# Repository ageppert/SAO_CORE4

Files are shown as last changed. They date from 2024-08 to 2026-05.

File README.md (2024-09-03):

# SAO_CORE4

A Nibble of Core Memory

Follow this project at: https://hackaday.io/project/197235-sao-core4-a-nibble-of-core-memory-with-i2c

Hardware Version 0.2.0 - Work in progres - reducing board size - add button - simplify.

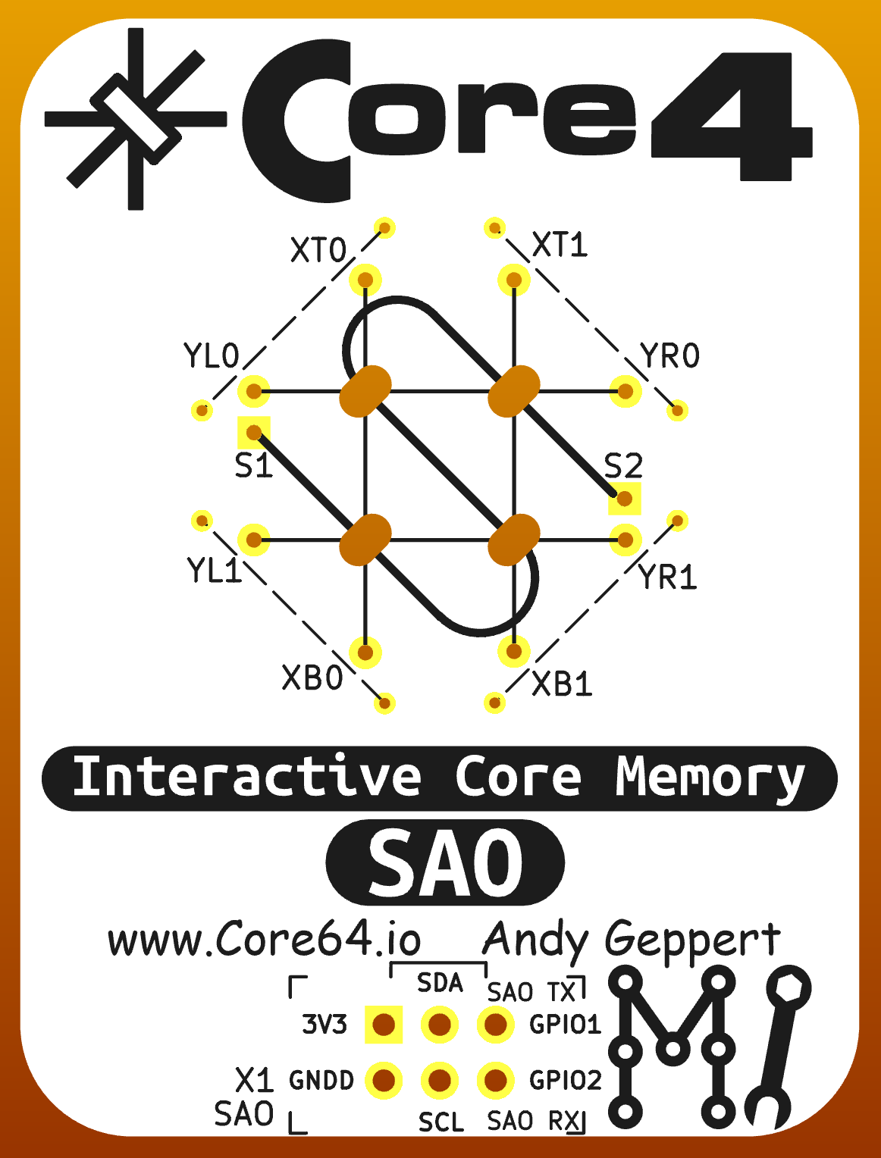
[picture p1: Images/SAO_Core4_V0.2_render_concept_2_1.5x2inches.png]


Hardware Version 0.1.1 hand reworked prototype, simplified and re-routed row drive transistor signals to simplify firmware development. This is the version that is currently the functional prototype. These changes will be in 0.2.0.

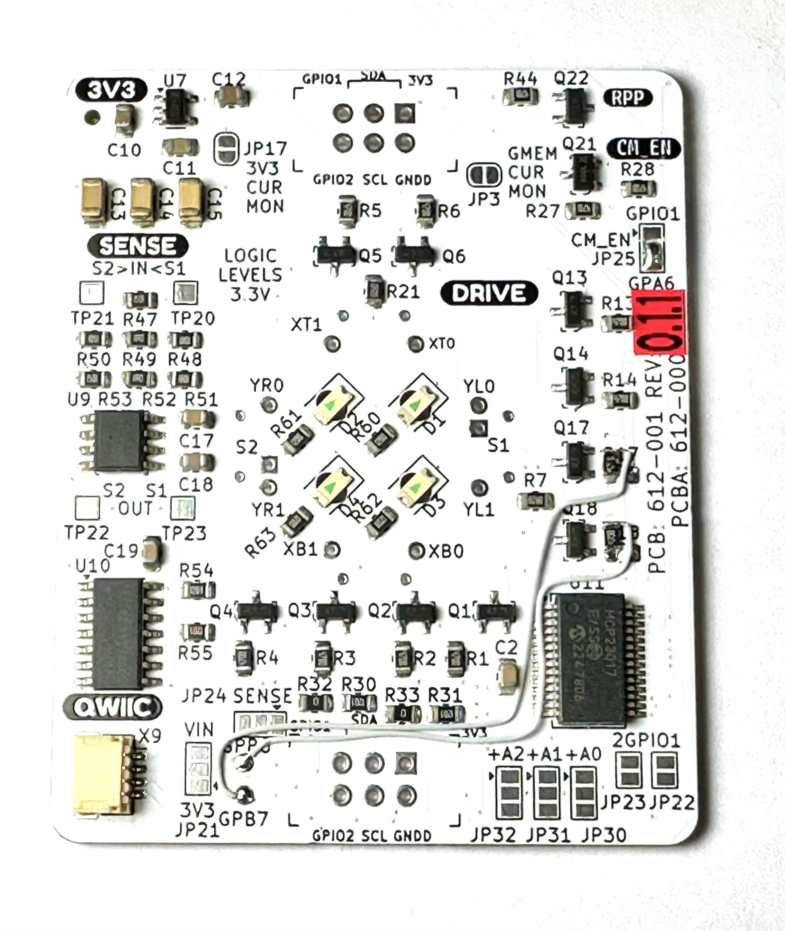
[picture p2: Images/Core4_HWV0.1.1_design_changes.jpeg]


Hardware Version 0.1 as prototyped

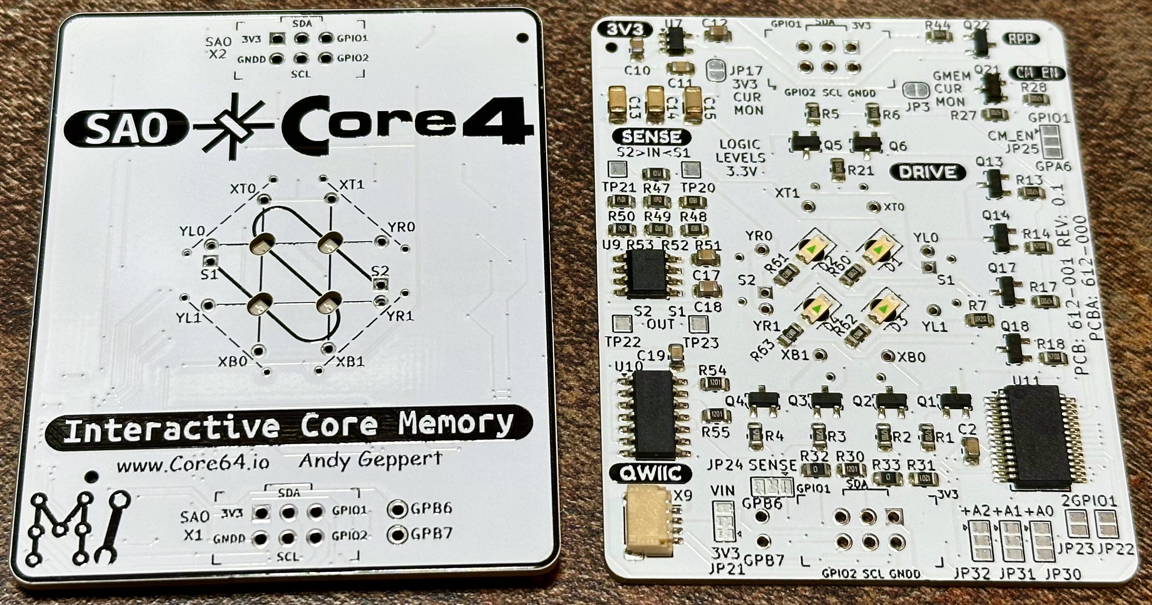
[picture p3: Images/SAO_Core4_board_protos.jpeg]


Hardware Version 0.1 render

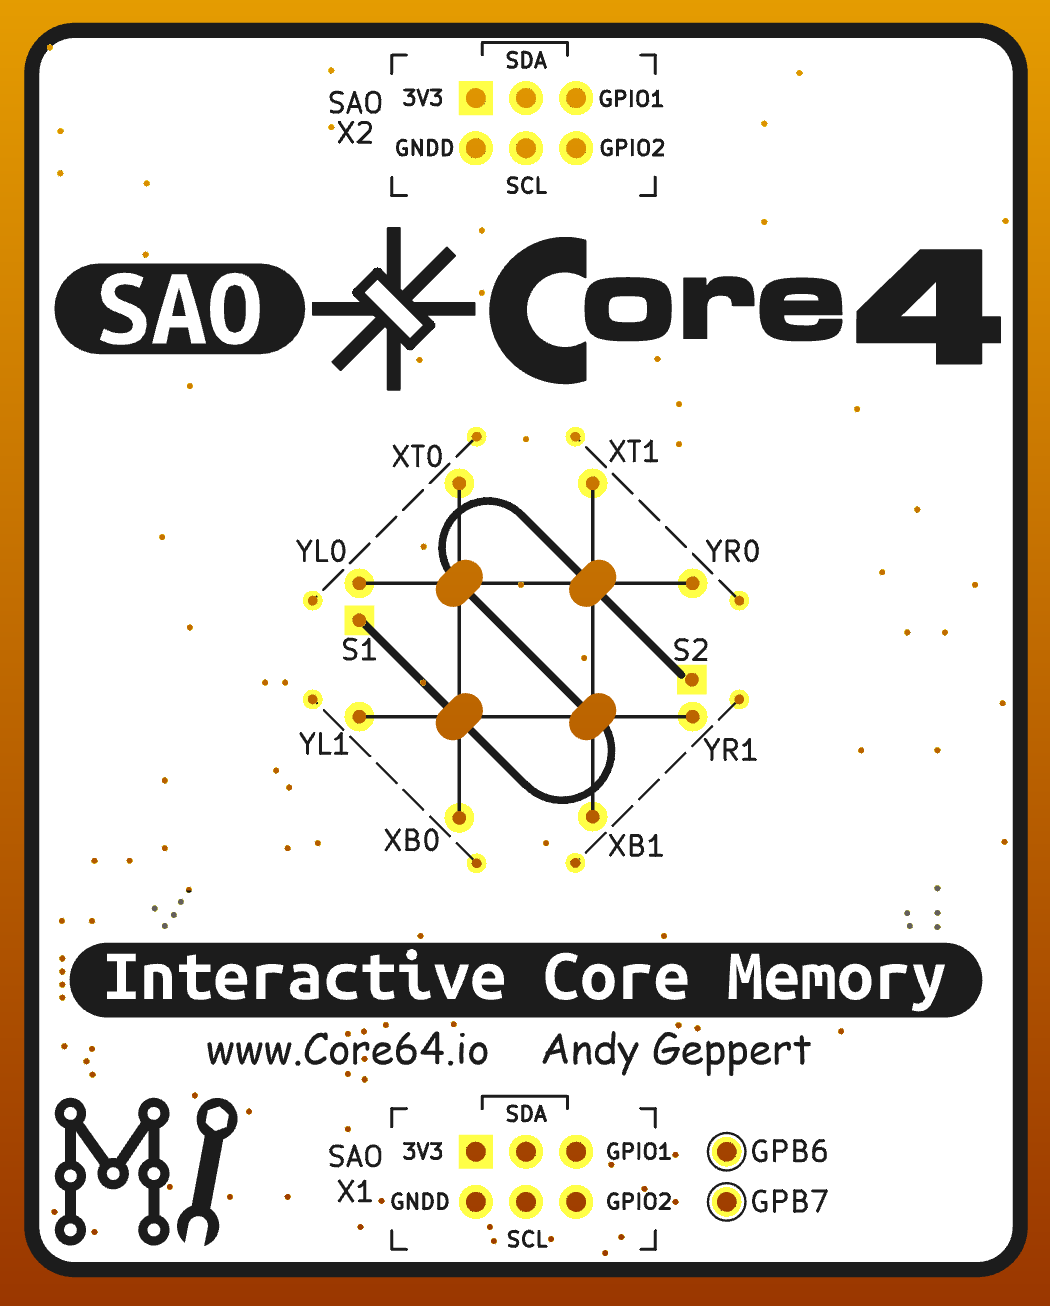
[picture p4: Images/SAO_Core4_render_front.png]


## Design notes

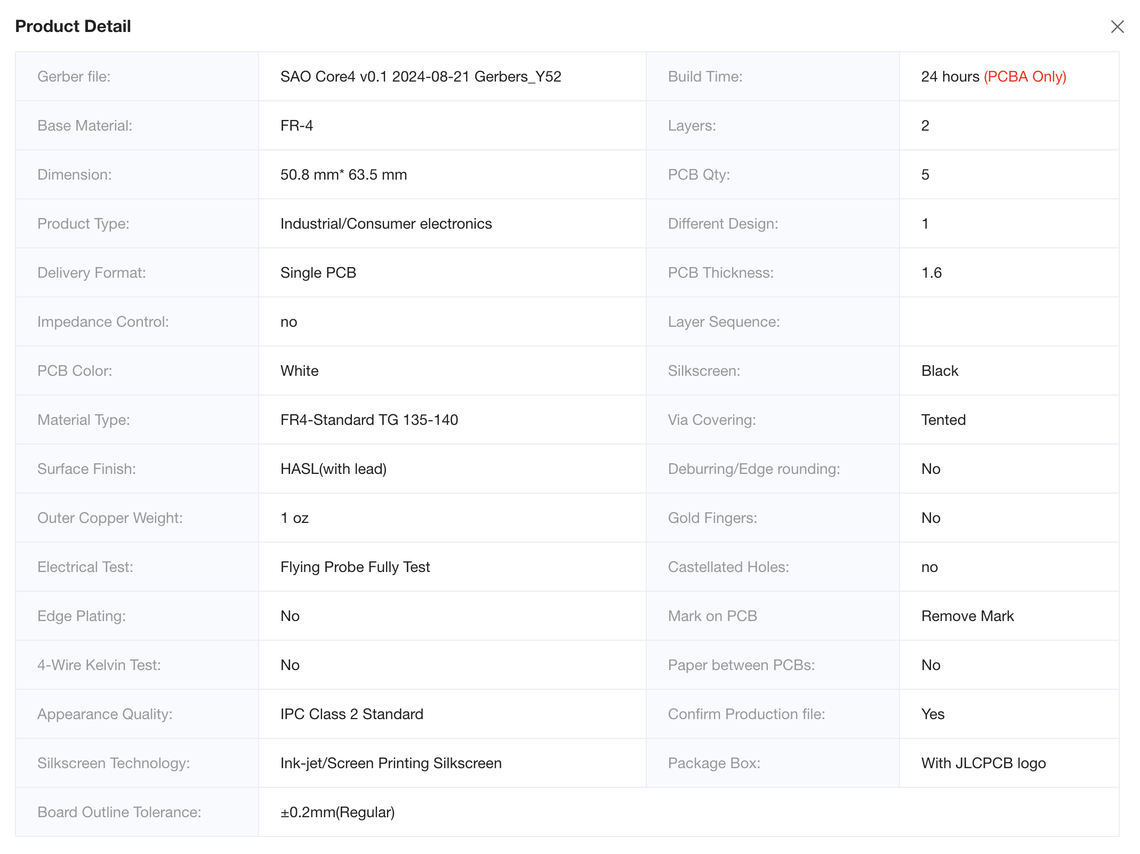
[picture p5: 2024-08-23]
Electronic Design/SAO_Core4_V0.1 Manufacturing (Qty 5)/Production Confirmation PCB Specs.png

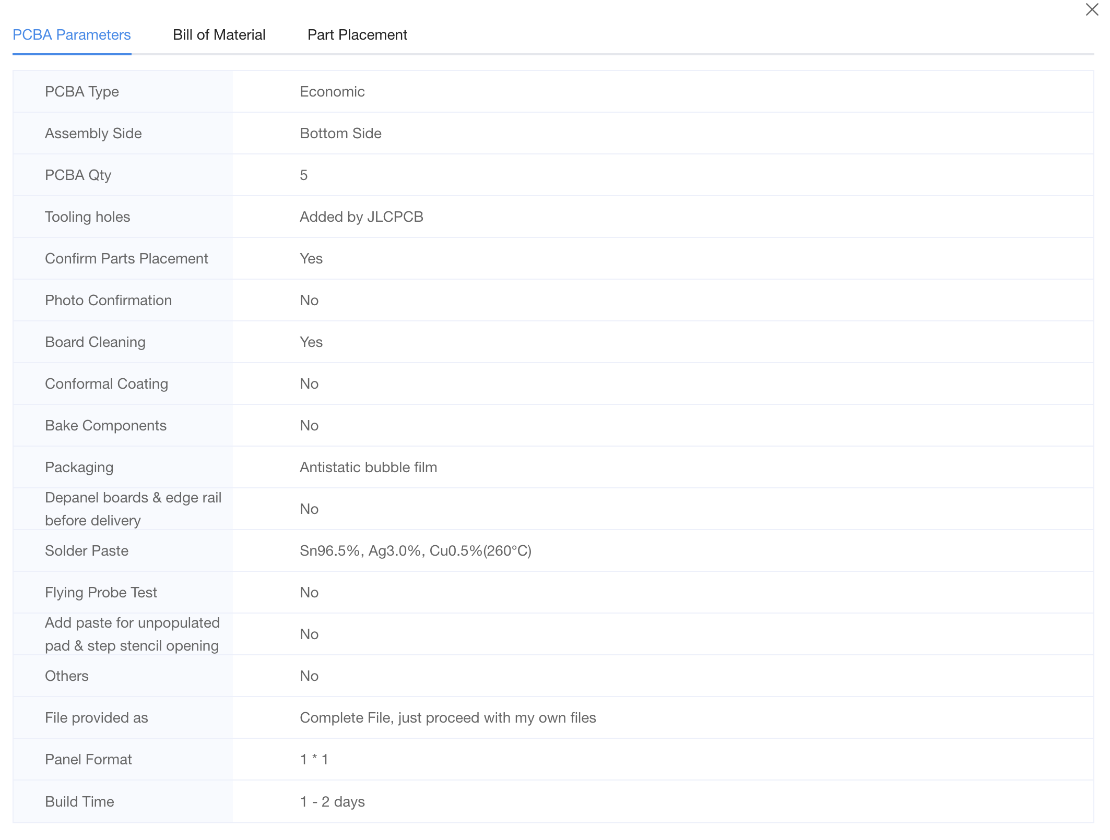
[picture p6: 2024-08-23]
Electronic Design/SAO_Core4_V0.1 Manufacturing (Qty 5)/Production Confirmation PCBA Specs.png

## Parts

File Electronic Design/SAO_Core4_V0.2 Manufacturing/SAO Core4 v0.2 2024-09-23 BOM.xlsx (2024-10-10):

Comment | Designator | Footprint | LCSC Part Number | Substituted
0.1uF | C2, C17, C19 | Capacitor_SMD:C_0805_2012Metric | C28233 | 3
1uF | C10, C12 | Capacitor_SMD:C_0805_2012Metric | C28323 | 2
0.01uF | C11 | Capacitor_SMD:C_0805_2012Metric | C1710 | 1
220uF | C13, C14, C15 | Capacitor_SMD:C_1206_3216Metric | C412252 | 3
10uF | C18 | Capacitor_SMD:C_0805_2012Metric | C17024 | 1
LED | D1, D2, D3, D4 | Andy_Footprint_Library:LED_1206_3216Metric_RevMnt_Hole1.8x2.4mm_custom | C3646936 | 4
MMBT4403LT1G | Q1, Q3, Q5, Q13, Q17 | digikey-footprints:SOT-23-3 | C78864 | 5
MMBT4401LT1G | Q2, Q4, Q6, Q14, Q18 | digikey-footprints:SOT-23-3 | C31776 | 5
Q_NMOS_DGS_AO3400A | Q21 | digikey-footprints:SOT-23-3 | C20917 | 1
470 | R1, R2, R3, R4, R5, R6, R13, R14, R17, R18, R28 | Resistor_SMD:R_0805_2012Metric | C17710 | 11
6R8-5% | R7, R21 | Resistor_SMD:R_0805_2012Metric | C17774 | 2
10K | R27, R30, R31, R54, R55 | Resistor_SMD:R_0805_2012Metric | C17414 | 5
1K5-1% | R47, R50, R53 | Resistor_SMD:R_0805_2012Metric | C4310 | 3
1K8-1% | R48, R51 | Resistor_SMD:R_0805_2012Metric | C17398 | 2
11-1% | R49, R52 | Resistor_SMD:R_0805_2012Metric | C17430 | 2
120 | R61, R62, R63, R64 | Resistor_SMD:R_0805_2012Metric | C17437 | 4
Button Edge EVQ-P7J01P | SW1 | Andy_Footprint_Library:SMD4_SW_EVQP7J_PAN | C2828254 | 1
SSP9193-33M5R | U7 | Package_TO_SOT_SMD:SOT-23-5 | C411022 | 1
LM393 | U9 | Andy_Footprint_Library:SOIC-8_W3.9mm | C7955 | 1
SN74HC02DR | U10 | Package_SO:SOIC-14_3.9x8.7mm_P1.27mm | C6809 | 1
MCP23017_SS | U11 | Package_SO:SSOP-28_5.3x10.2mm_P0.65mm | C506653 | 1

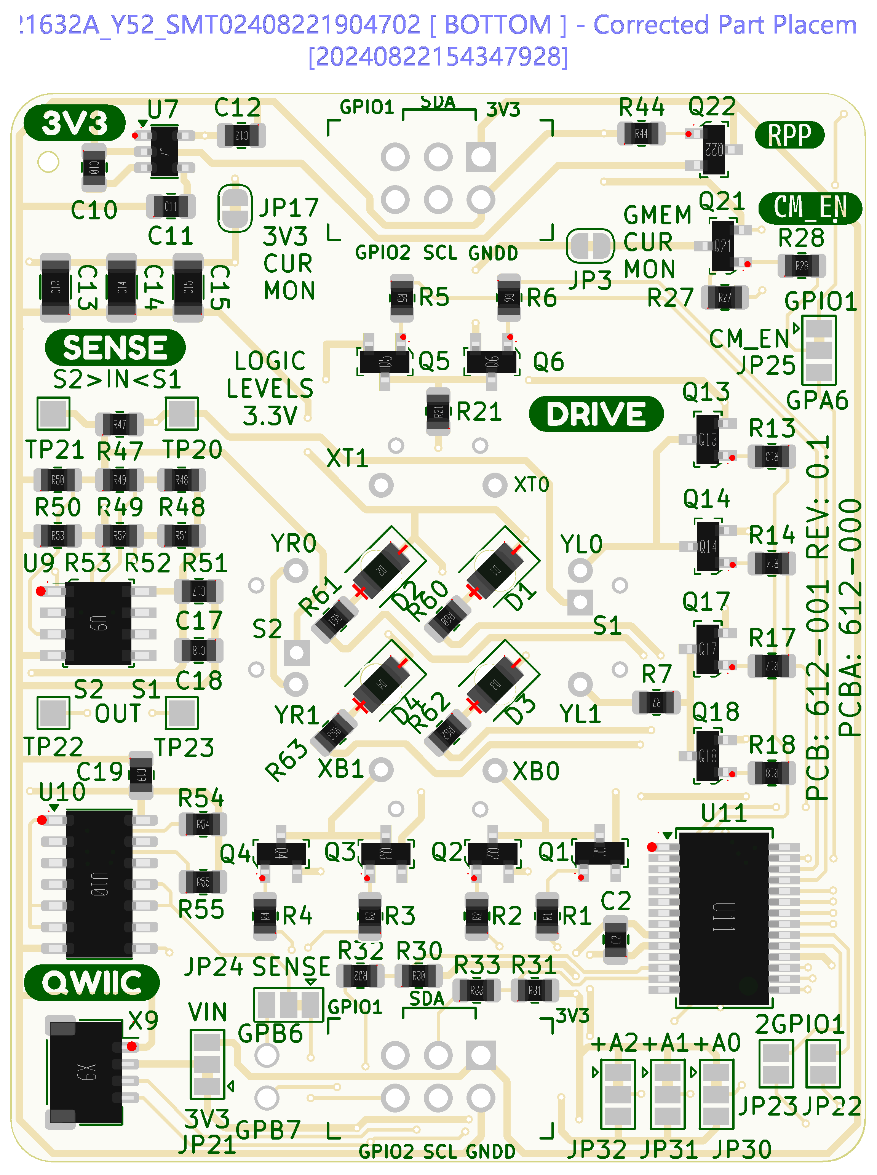
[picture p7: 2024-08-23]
Electronic Design/SAO_Core4_V0.1 Manufacturing (Qty 5)/Production Confirmation Parts Placement.png

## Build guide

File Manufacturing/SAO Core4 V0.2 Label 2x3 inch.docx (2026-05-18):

SAO CORE4 KIT V0.2 [ ] Qty 1, SAO Core4 PCBA [ ] Qty 1, SAO Shrouded Header 2x3 pin [ ] Qty 1, Enameled Wire, 32AWG, 600mm (24 in.) [ ] Qty 6, Ferrite Core Memory bits [ ] Qty 3, Screen Protector 17x17mm [ ] Qty 1, Magnetic Stylus, 3mm magnets https://hackaday.io/project/197235 https://github.com/ageppert/SAO_CORE4 | SAO CORE4 KIT V0.2 [ ] Qty 1, SAO Core4 PCBA [ ] Qty 1, SAO Shrouded Header 2x3 pin [ ] Qty 1, Enameled Wire, 32AWG, 600mm (24 in.) [ ] Qty 6, Ferrite Core Memory bits [ ] Qty 3, Screen Protector 17x17mm [ ] Qty 1, Magnetic Stylus, 3mm magnets https://hackaday.io/project/197235 https://github.com/ageppert/SAO_CORE4
SAO CORE4 KIT V0.2 [ ] Qty 1, SAO Core4 PCBA [ ] Qty 1, SAO Shrouded Header 2x3 pin [ ] Qty 1, Enameled Wire, 32AWG, 600mm (24 in.) [ ] Qty 6, Ferrite Core Memory bits [ ] Qty 3, Screen Protector 17x17mm [ ] Qty 1, Magnetic Stylus, 3mm magnets https://hackaday.io/project/197235 https://github.com/ageppert/SAO_CORE4 | SAO CORE4 KIT V0.2 [ ] Qty 1, SAO Core4 PCBA [ ] Qty 1, SAO Shrouded Header 2x3 pin [ ] Qty 1, Enameled Wire, 32AWG, 600mm (24 in.) [ ] Qty 6, Ferrite Core Memory bits [ ] Qty 3, Screen Protector 17x17mm [ ] Qty 1, Magnetic Stylus, 3mm magnets https://hackaday.io/project/197235 https://github.com/ageppert/SAO_CORE4
SAO CORE4 KIT V0.2 [ ] Qty 1, SAO Core4 PCBA [ ] Qty 1, SAO Shrouded Header 2x3 pin [ ] Qty 1, Enameled Wire, 32AWG, 600mm (24 in.) [ ] Qty 6, Ferrite Core Memory bits [ ] Qty 3, Screen Protector 17x17mm [ ] Qty 1, Magnetic Stylus, 3mm magnets https://hackaday.io/project/197235 https://github.com/ageppert/SAO_CORE4 | SAO CORE4 KIT V0.2 [ ] Qty 1, SAO Core4 PCBA [ ] Qty 1, SAO Shrouded Header 2x3 pin [ ] Qty 1, Enameled Wire, 32AWG, 600mm (24 in.) [ ] Qty 6, Ferrite Core Memory bits [ ] Qty 3, Screen Protector 17x17mm [ ] Qty 1, Magnetic Stylus, 3mm magnets https://hackaday.io/project/197235 https://github.com/ageppert/SAO_CORE4
SAO CORE4 KIT V0.2 [ ] Qty 1, SAO Core4 PCBA [ ] Qty 1, SAO Shrouded Header 2x3 pin [ ] Qty 1, Enameled Wire, 32AWG, 600mm (24 in.) [ ] Qty 6, Ferrite Core Memory bits [ ] Qty 3, Screen Protector 17x17mm [ ] Qty 1, Magnetic Stylus, 3mm magnets https://hackaday.io/project/197235 https://github.com/ageppert/SAO_CORE4 | SAO CORE4 KIT V0.2 [ ] Qty 1, SAO Core4 PCBA [ ] Qty 1, SAO Shrouded Header 2x3 pin [ ] Qty 1, Enameled Wire, 32AWG, 600mm (24 in.) [ ] Qty 6, Ferrite Core Memory bits [ ] Qty 3, Screen Protector 17x17mm [ ] Qty 1, Magnetic Stylus, 3mm magnets https://hackaday.io/project/197235 https://github.com/ageppert/SAO_CORE4
SAO CORE4 KIT V0.2 [ ] Qty 1, SAO Core4 PCBA [ ] Qty 1, SAO Shrouded Header 2x3 pin [ ] Qty 1, Enameled Wire, 32AWG, 600mm (24 in.) [ ] Qty 6, Ferrite Core Memory bits [ ] Qty 3, Screen Protector 17x17mm [ ] Qty 1, Magnetic Stylus, 3mm magnets https://hackaday.io/project/197235 https://github.com/ageppert/SAO_CORE4 | SAO CORE4 KIT V0.2 [ ] Qty 1, SAO Core4 PCBA [ ] Qty 1, SAO Shrouded Header 2x3 pin [ ] Qty 1, Enameled Wire, 32AWG, 600mm (24 in.) [ ] Qty 6, Ferrite Core Memory bits [ ] Qty 3, Screen Protector 17x17mm [ ] Qty 1, Magnetic Stylus, 3mm magnets https://hackaday.io/project/197235 https://github.com/ageppert/SAO_CORE4

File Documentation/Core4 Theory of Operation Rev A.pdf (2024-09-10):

.io

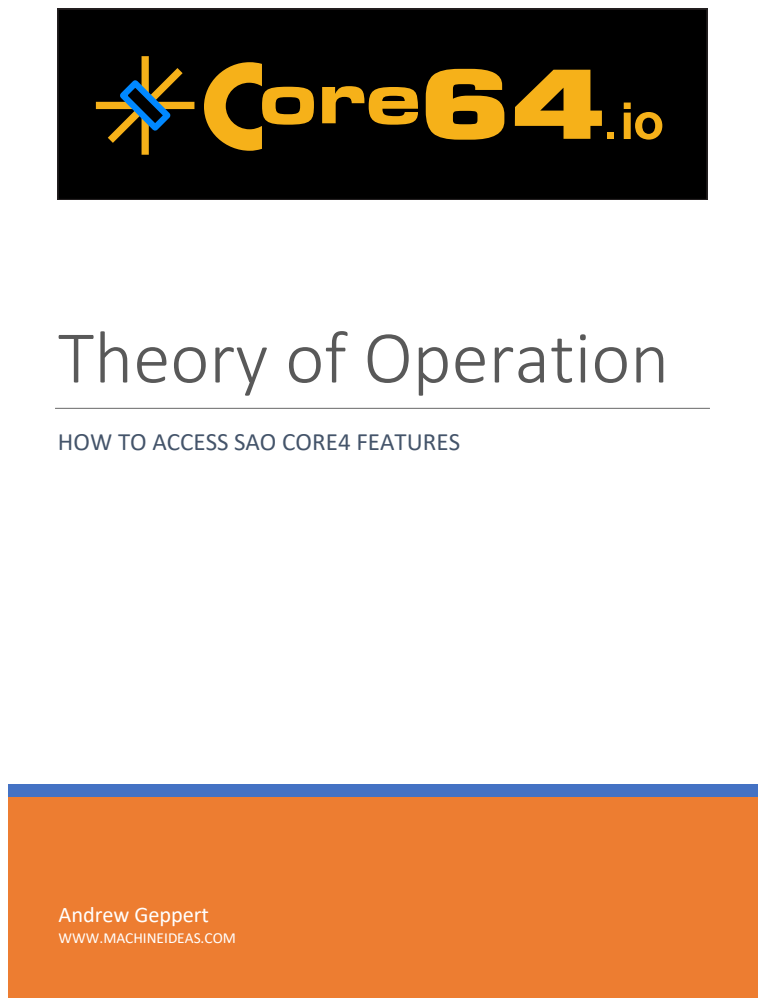
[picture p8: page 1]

Theory of Operation

HOW TO ACCESS SAO CORE4 FEATURES

Andrew Geppert
WWW.MACHINEIDEAS.COM

Core4 Theory of Operation | www.Core64.io | 2

## 1. TABLE OF CONTENTS

## 2. Version History of This Guide

Revision | Description | Author | Date
A | First draft | Andy Geppert | 2024-09-10

The latest version of this and related Core4 details at: https://github.com/ageppert/SAO_CORE4

Demo video on YouTube: https://www.youtube.com/watch?v=id1_PEvV3Vw

Concept and design by Andy Geppert at www.MachineIdeas.com

## 3. Important Cautions and Warnings

Beware the ESD monster!

Core4 Maximum battery pack voltage: 5.5 VDC All kits have minimum working voltage: 3 VDC

CORES are fragile! Don’t crush them.

CORES are small! Don’t lose them.

⚠ These caution symbols point out important things to help ensure your assembly goes smoothly!

## 4. Introduction

This guide covers the theory of operation and how to interface with the SAO Core4.

## 5. Control Signals

Control of the core matrix and LEDs is through an SAO port. Learn more about the SAO standard: https://docs.google.com/document/d/1EJqvkkLMAPsQ9VWF5A4elWoi0qMlKyr5Giw5rqRmtnM/edit?usp=sharing

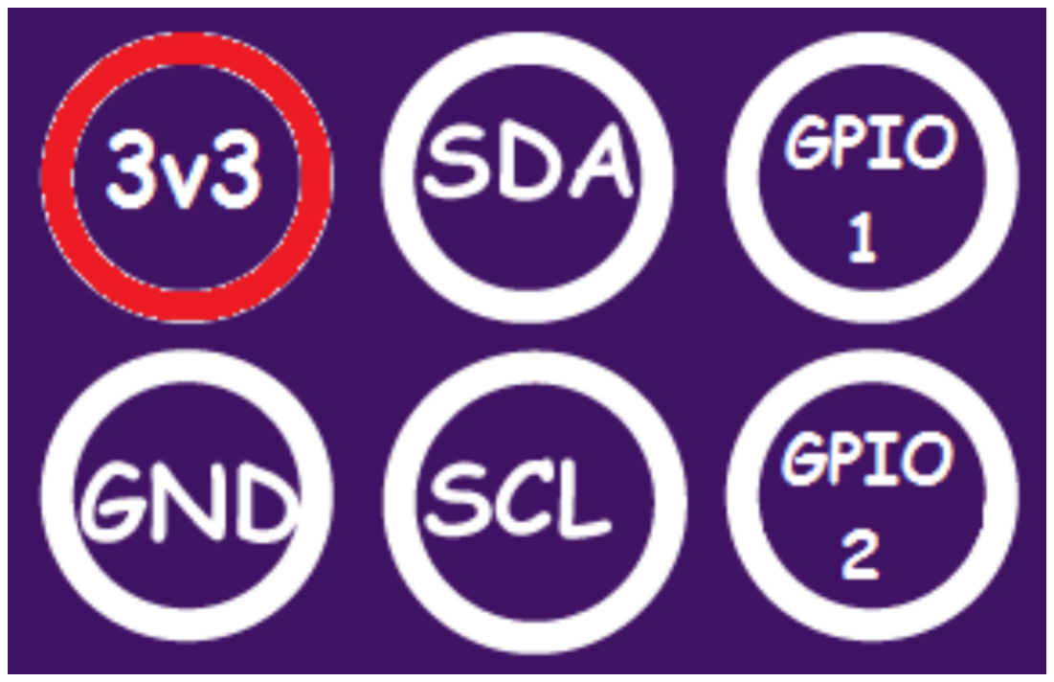
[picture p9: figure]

The I2C signals (SDA and SCL) connect to a single MCP23017 I2C IO Expander with a default address of 0x27 (Decimal 39). The sixteen MCP23017 GPIOs are all meant to be configured as outputs for use with Core4. These outputs are:
- 4 LEDs (high to enable)
- 10 core matrix drive transistors
- 1 common core memory drive enable MOSFET
- 1 sense circuit reset

GPIO 1 is used for an optional input button, to be configured with the associated MCU input set with pull-up enabled. When the button is pressed, GPIO 1 is expected to transition from high to low.

GPIO 2 is needed as the Sense signal input into the associated MCU. This is normally low, but goes high when a core changes state.

## 6. Controlling the LEDS

The LEDs are controlled by the MCP23017 output lines. High to turn on the LED, low to turn off.

PCBA Hardware Version 0.1.x:
GPB2 is LED 1, aka Pixel 0
GPB3 is LED 2, aka Pixel 1
GPB4 is LED 3, aka Pixel 2 GPB5 is LED 4, aka Pixel 3

⚠ An external MCU is required to operate SAO Core4. All control logic is 3.3 Volts.

## 7. Controlling Core Memory

Introduction

Core memory can only be written to. It is non-volatile. But it requires a write in order to read the state of the core. This is called a “destructive read.”

If the magnetic field of a core changes, when written too, there is a very small voltage induced in the sense wire, which is common to all the cores. Thus, only a single core should be written to at one time, in order to be able to detect its state.

If a core changes state when written too, as indicated by the sense wire signal, the core will need to be written again to the prior state.

A core state change will NOT occur if the magnetic stylus is near the given core. The absence of this state change, when it was expected to have occurred, is used by the MCU logic to determine the presence of the magnetic stylus.

Some great resources to learn more:
Curious Marc: https://www.youtube.com/watch?v=AwsInQLmjXc&t=1094s&ab_channel=CuriousMarc

Jerry Walker: https://www.youtube.com/watch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

Andy Geppert: https://www.youtube.com/watch?v=5HAyPMMNyDc&list=PLgr0YZUR4CSUvSYynSjwbAt1JiIod-NOV&ab_channel=AndyGeppert

Prepare to Sense

Follow along with the schematic to help out: https://github.com/ageppert/SAO_CORE4/tree/main/Electronic%20Design/SAO_Core4_V0.1.1%20Schematic

Prior to writing to a core, reset the sense circuit (sense signal output latch) by briefly driving CM_SNS_RST high via the MCP23017 IO Expander. Bring the CM_SNS_RST low, and make sure the Core Matrix Enable (CM_EN) is low at the same time.

Activate the Matrix

Each core is accessed by activating four transistors associated with the row and column which intersects with the chosen core. A final MOSFET is briefly enabled (CM_EN) to allow current to flow through the transistors. Additionally, a passive sense circuit will capture and store the sense signal, if present (when a core flips polarity), into the Sense Signal Output Latch.
- QxN (NPN) is normally low, high to activate matrix transistor.
- QxP (PNP) is normally high, low to activate matrix transistor.
- Q21 CM_EN MOSFET is normally low, high to activate the entire matrix.

Deactivate the Matrix

After the CM_EN is returned low, and the matrix driver transistors are disabled, the CM_SNS_PLS may be checked via GPIO2 of the SAO port. If this signal is high, that means a core changed polarity.

## 8. Troubleshooting

Each time a row or column is accessed, there should be a voltage drop across both matrix drive current limiting resistors, R7 and R21. The drop should be approximately 2 volts. If the voltage drop is not occurring then check:
- Continuity through the matrix wires.
- Correct transistors are being enabled.
- Core Memory Enable is enabled briefly.

If the current is flowing through the matrix wires, then check the sense output pulse signal (CM_SNS_PLS) when alternating the flow of current through a given core. Be sure to reset the sense circuit (CM_SNS_RST) between each alternate pulse of current.

There will be no sense signal detected if the current in two pulses to the core is in the same direction. It must alternate.

If the sense signal pulse is not present, verify continuity through the sense wire at either the solder pads S1 and S2 or the open ends of R47.

You may also find support here: https://discord.gg/nPcTNNfMmd

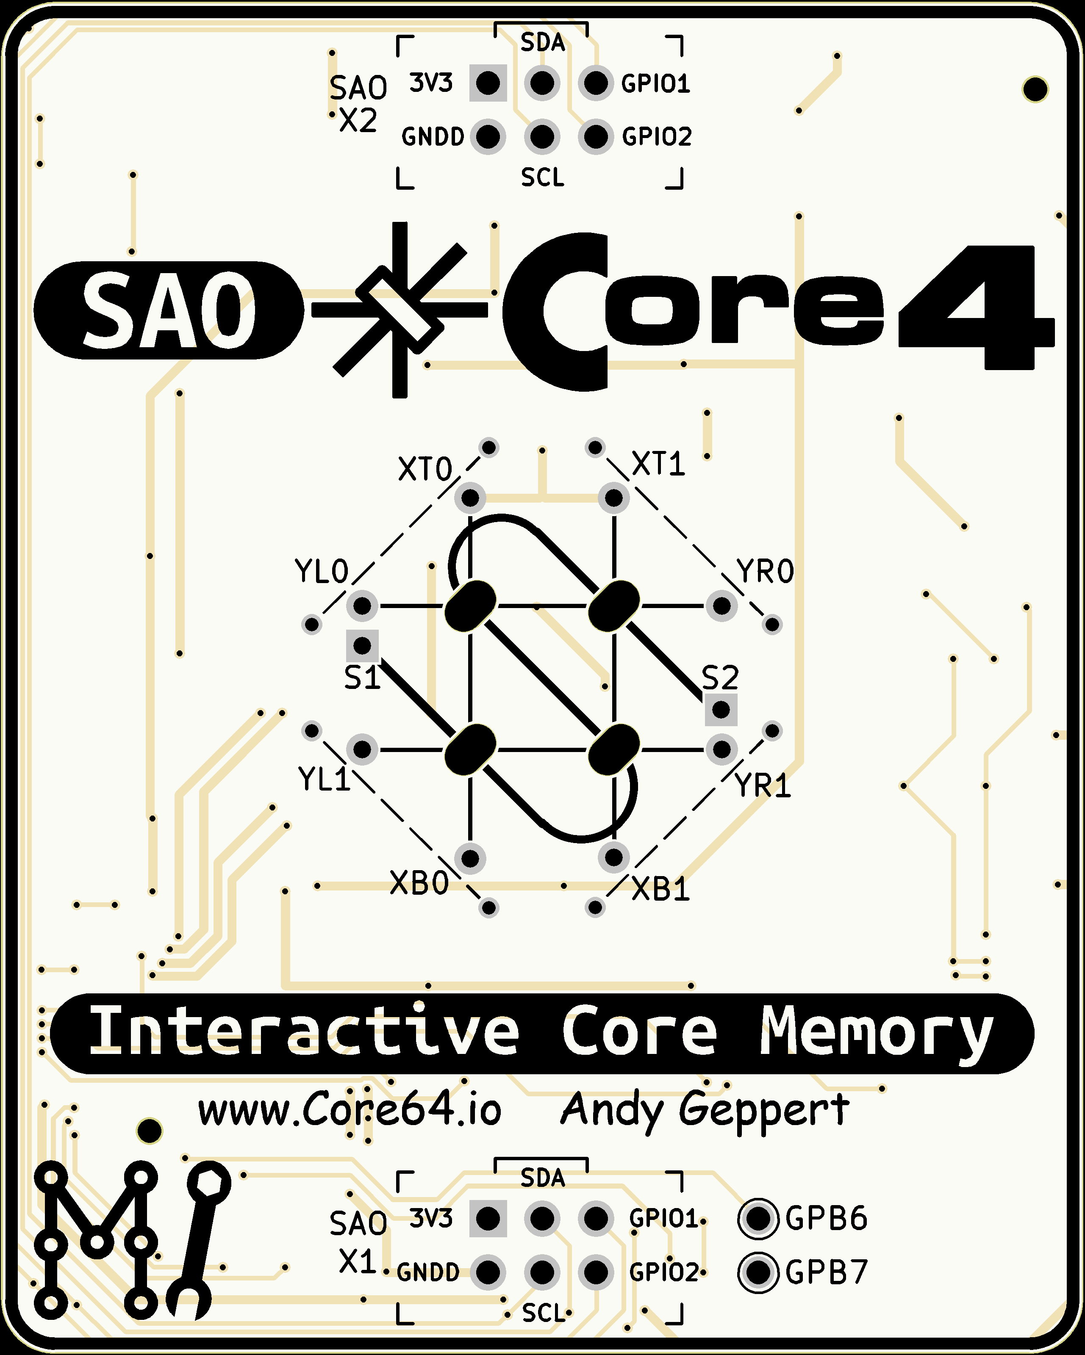
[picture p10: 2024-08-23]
Electronic Design/SAO_Core4_V0.1 Manufacturing (Qty 5)/Production Confirmation Front.png

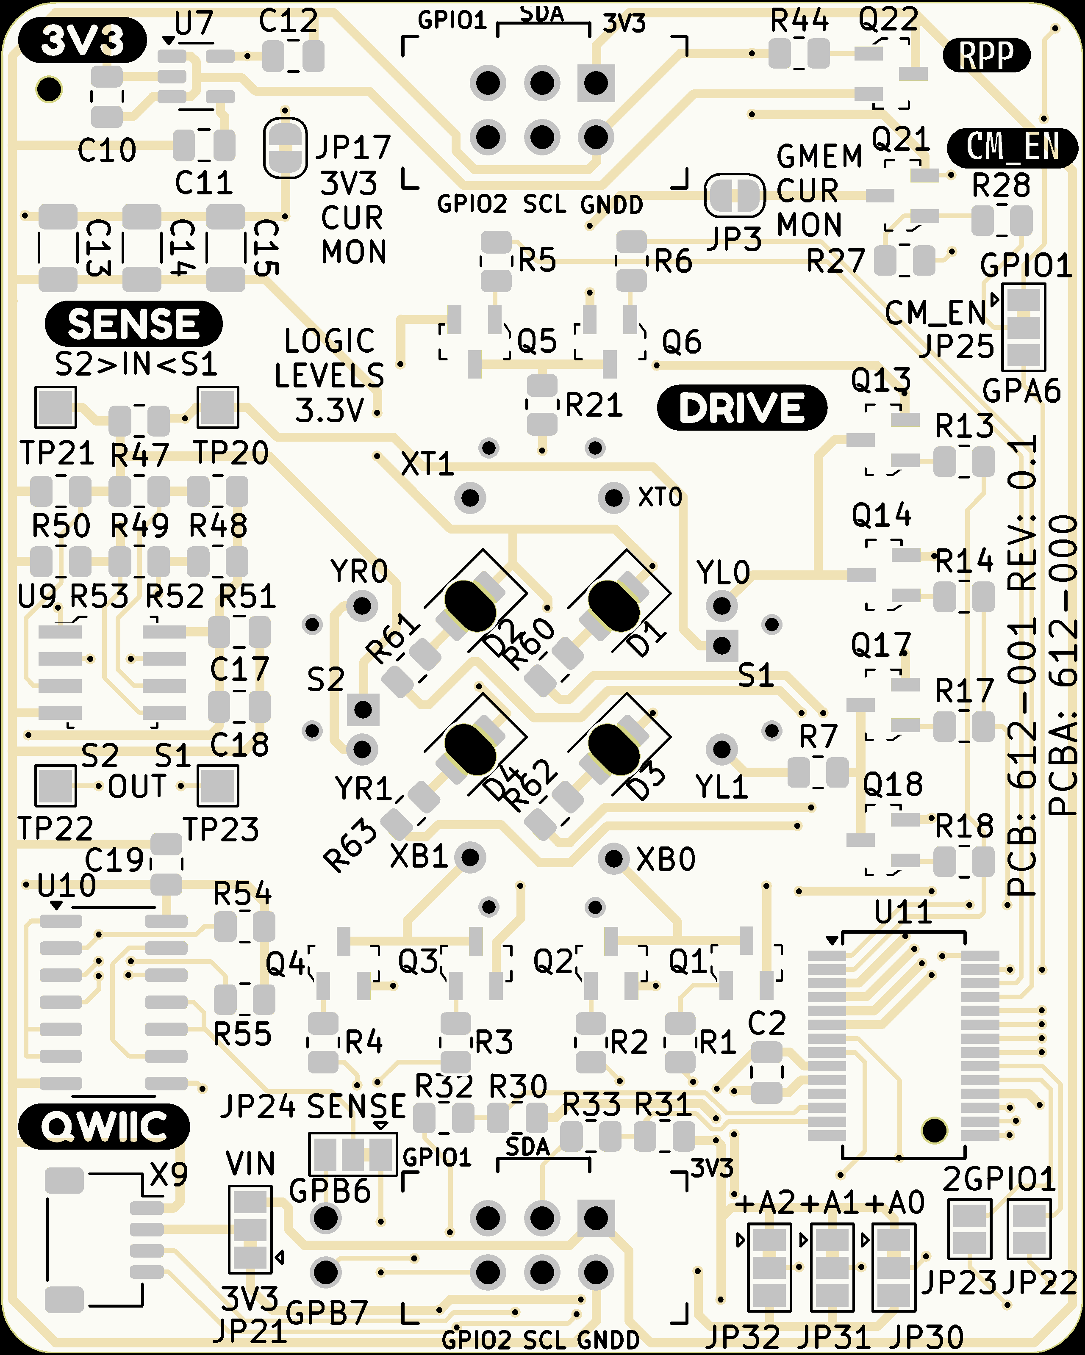
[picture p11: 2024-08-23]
Electronic Design/SAO_Core4_V0.1 Manufacturing (Qty 5)/Production Confirmation Back.png

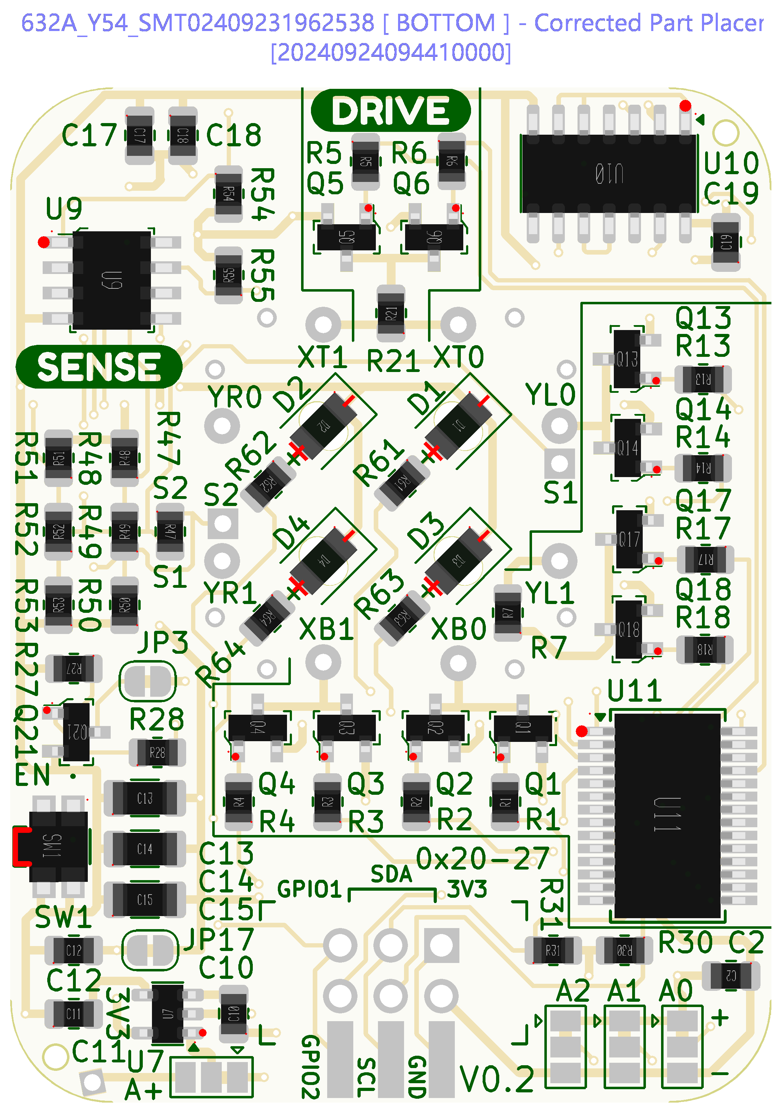
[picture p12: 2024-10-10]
Electronic Design/SAO_Core4_V0.2 Manufacturing/4654471168-Produce_DanZhi.SMT_Snapshot.Bottom.2721632A_Y54.SMT02409231962538.png

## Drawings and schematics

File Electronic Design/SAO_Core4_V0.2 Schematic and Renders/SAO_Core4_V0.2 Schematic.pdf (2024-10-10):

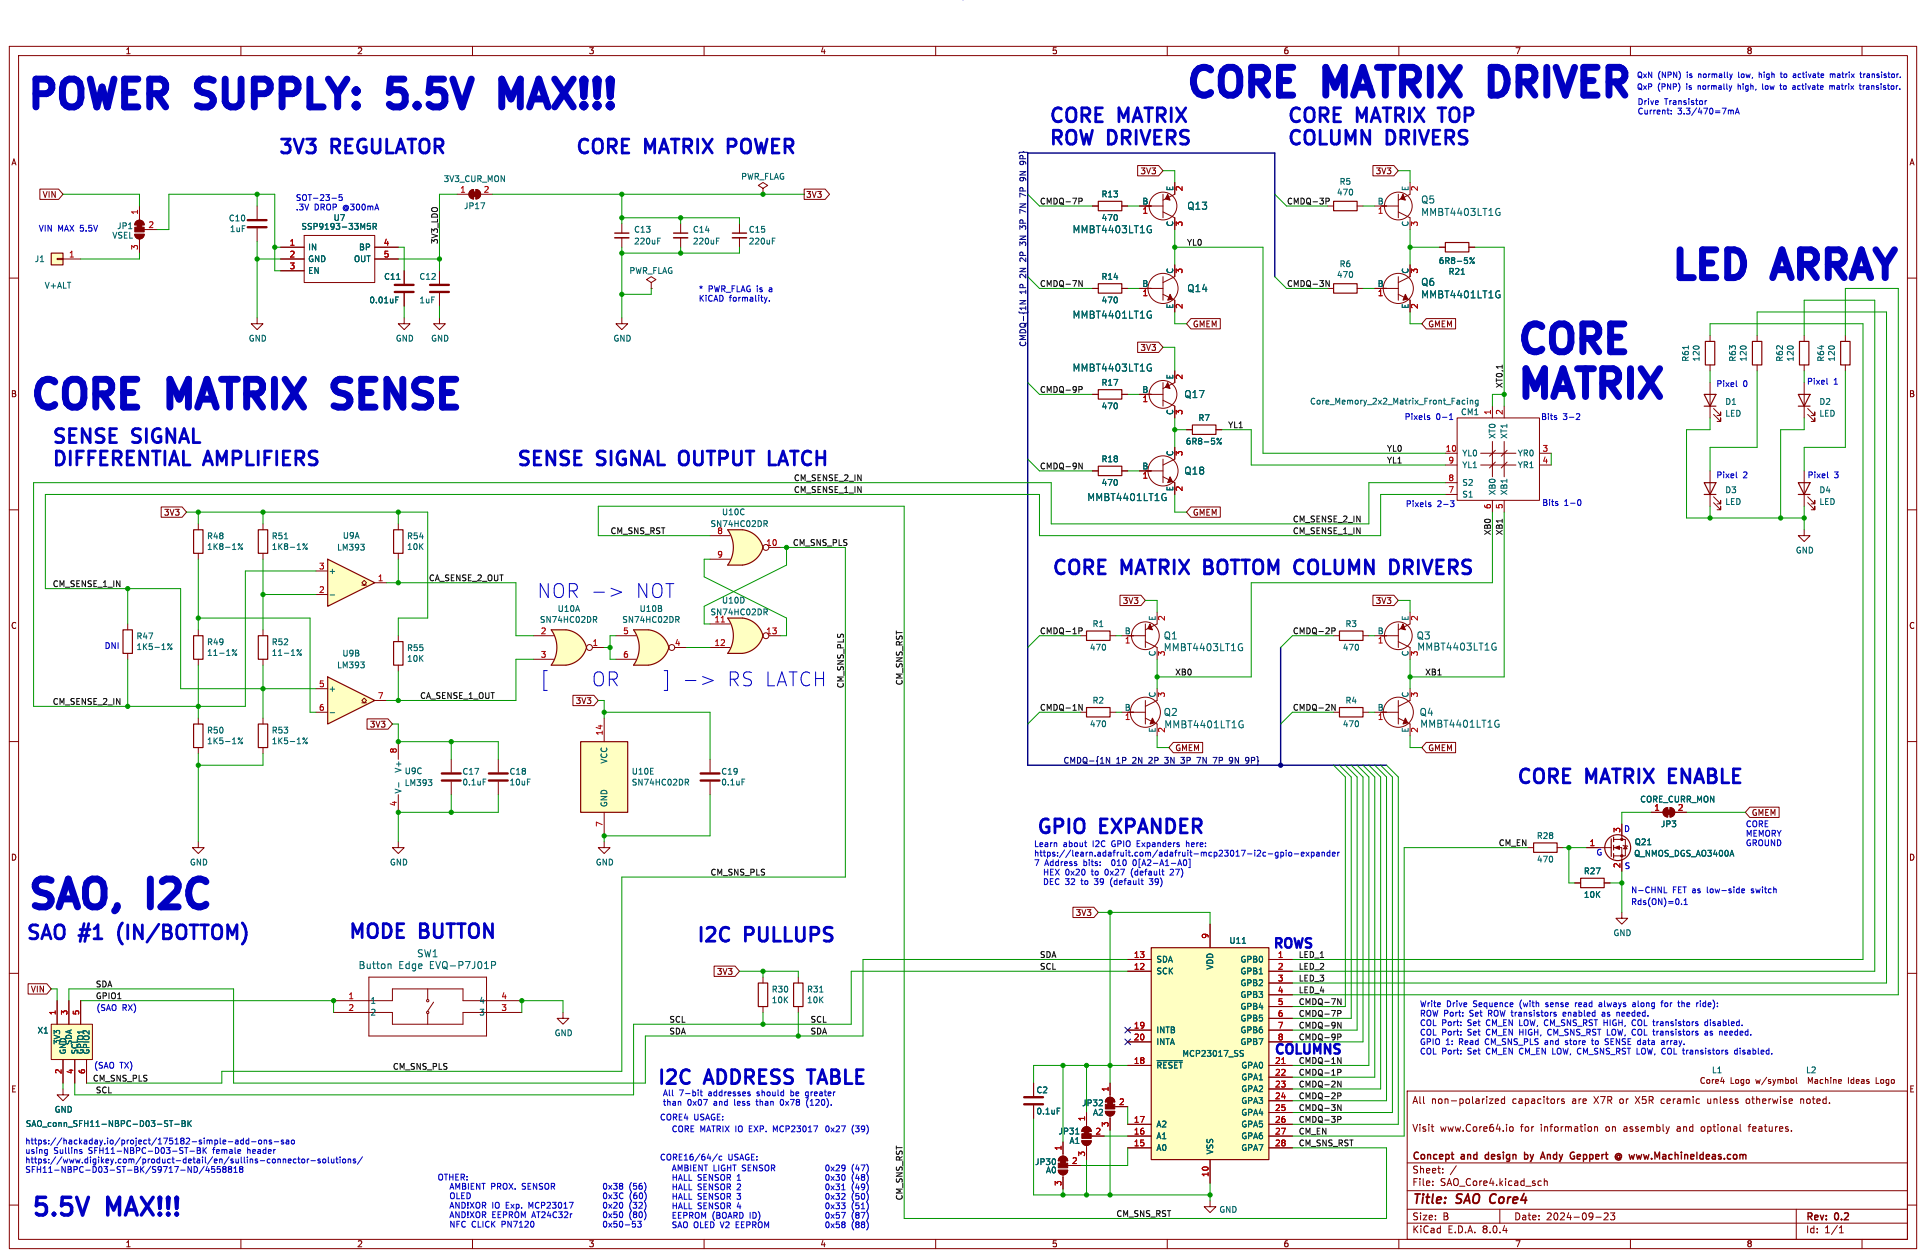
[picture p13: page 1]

CORE MATRIX DRIVERDrive Transistor Current: 3.3/470=7mA MODE BUTTON
COLUMN DRIVERS

3 U11 MCP23017_SS GPB0 1 VSS 10 SCK 12 SDA 13 A0 15 A1 16 A2 17 ~{RESET} 18

CORE MATRIX BOTTOM COLUMN DRIVERS

1 GND
AND!XOR IO Exp. MCP23017 AND!XOR EEPROM AT24C32r NFC CLICK PN7120 X1 SAO_conn_SFH11-NBPC-D03-ST-BK 3V3

6 X1 SAO_conn_SFH11-NBPC-D03-ST-BK GND

than 0x07 and less than 0x78 (120).

CORE MATRIX IO EXP. MCP23017 CORE4 USAGE: 0x38 (56) 0x3C (60) 0x20 (32) 0x50 (80) 0x50-53

https://hackaday.io/project/175182-simple-add-ons-sao
5.5V MAX!!!

AMBIENT PROX. SENSOR OLED

HALL SENSOR 1 HALL SENSOR 2 HALL SENSOR 3 HALL SENSOR 4 EEPROM (BOARD ID) SAO OLED V2 EEPROM

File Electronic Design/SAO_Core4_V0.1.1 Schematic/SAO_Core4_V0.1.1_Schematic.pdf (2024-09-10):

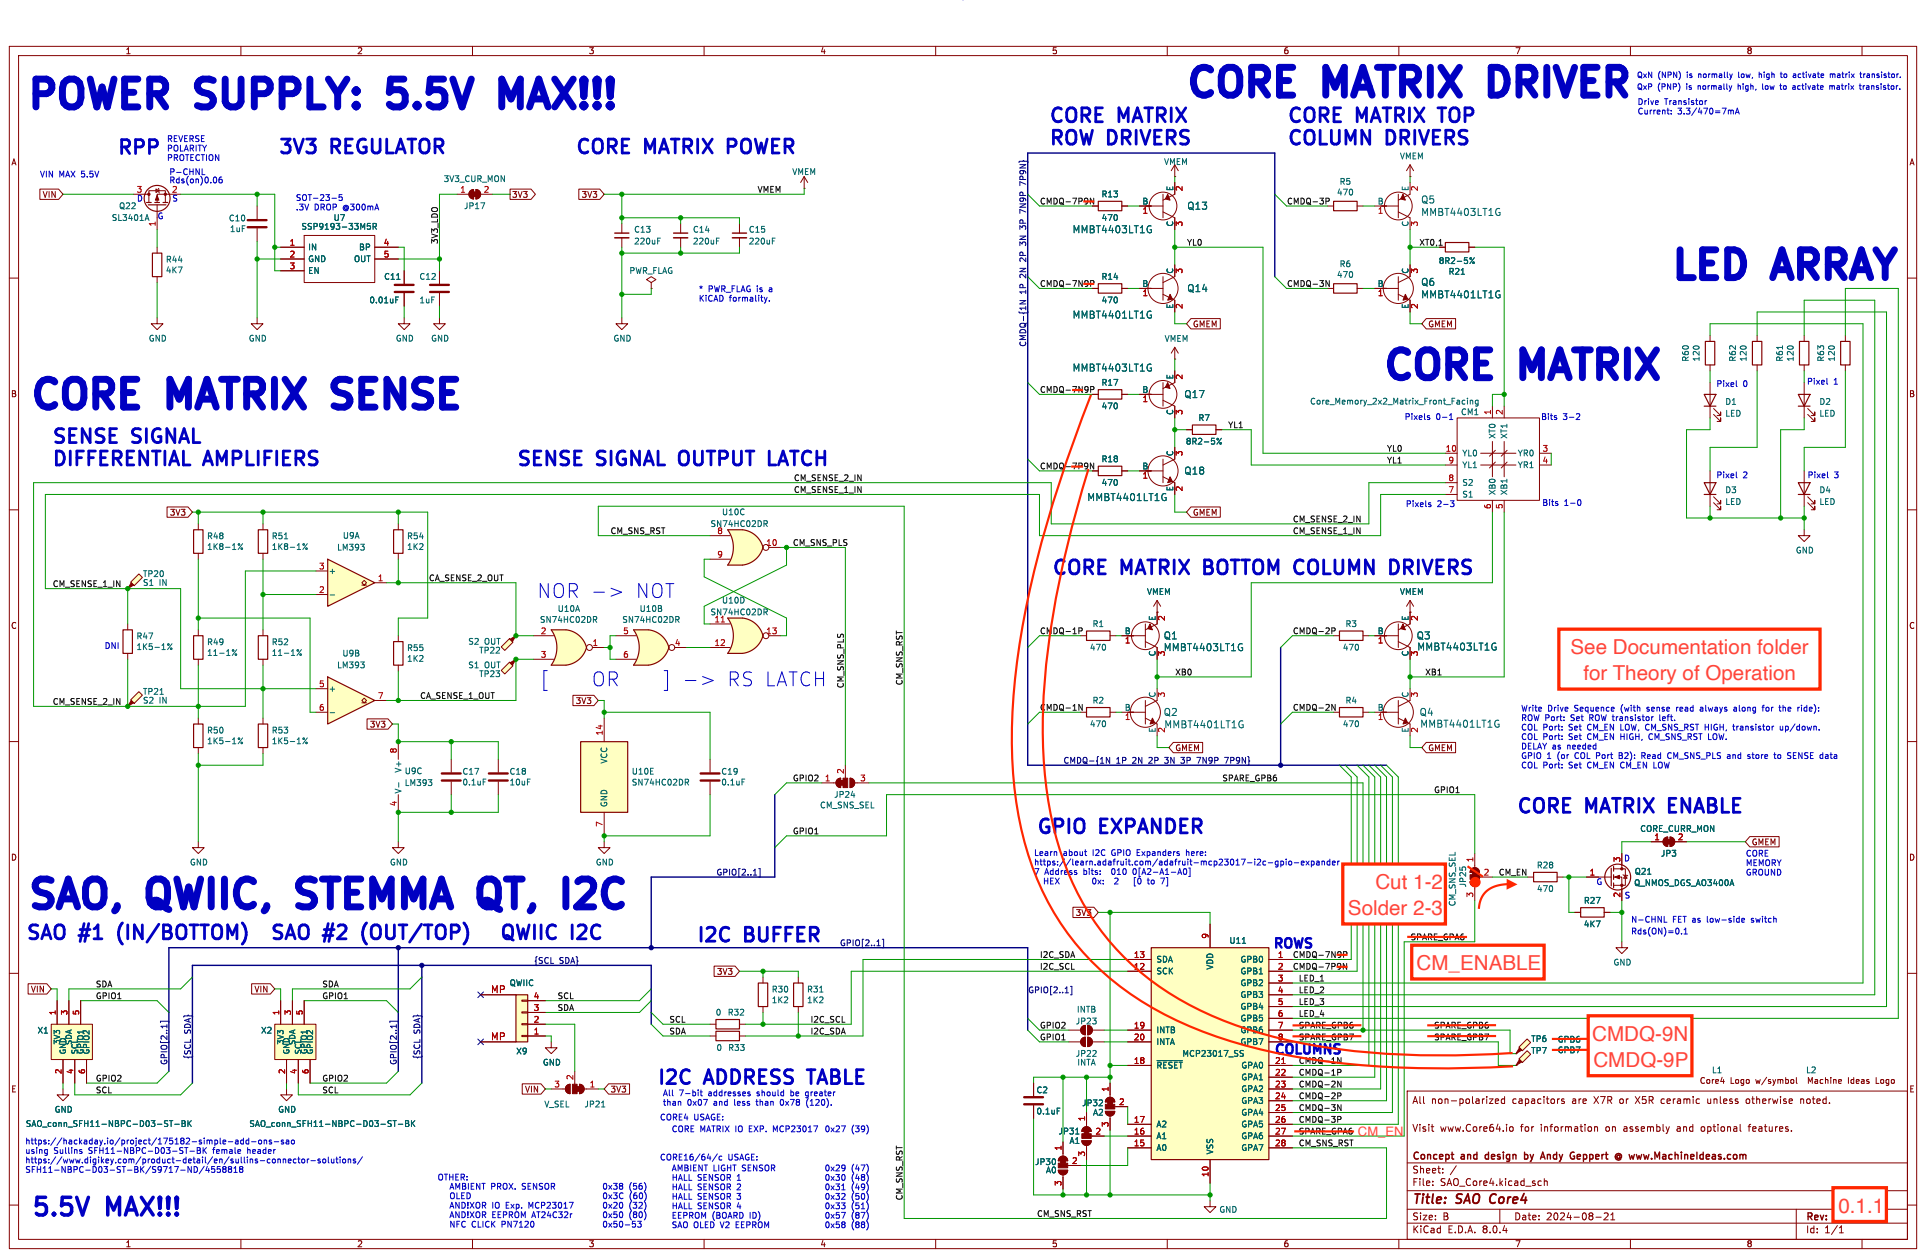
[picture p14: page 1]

Bits 1-0 CORE MATRIX POWER

SENSE SIGNAL OUTPUT LATCH

CORE MATRIX BOTTOM COLUMN DRIVERS

{SCL SDA}

6 X1 SAO_conn_SFH11-NBPC-D03-ST-BK GND

than 0x07 and less than 0x78 (120).
CORE4 USAGE:
CORE MATRIX IO EXP. MCP23017

https://hackaday.io/project/175182-simple-add-ons-sao

AMBIENT PROX. SENSOR OLED

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

AND!XOR IO Exp. MCP23017 AND!XOR EEPROM AT24C32r NFC CLICK PN7120

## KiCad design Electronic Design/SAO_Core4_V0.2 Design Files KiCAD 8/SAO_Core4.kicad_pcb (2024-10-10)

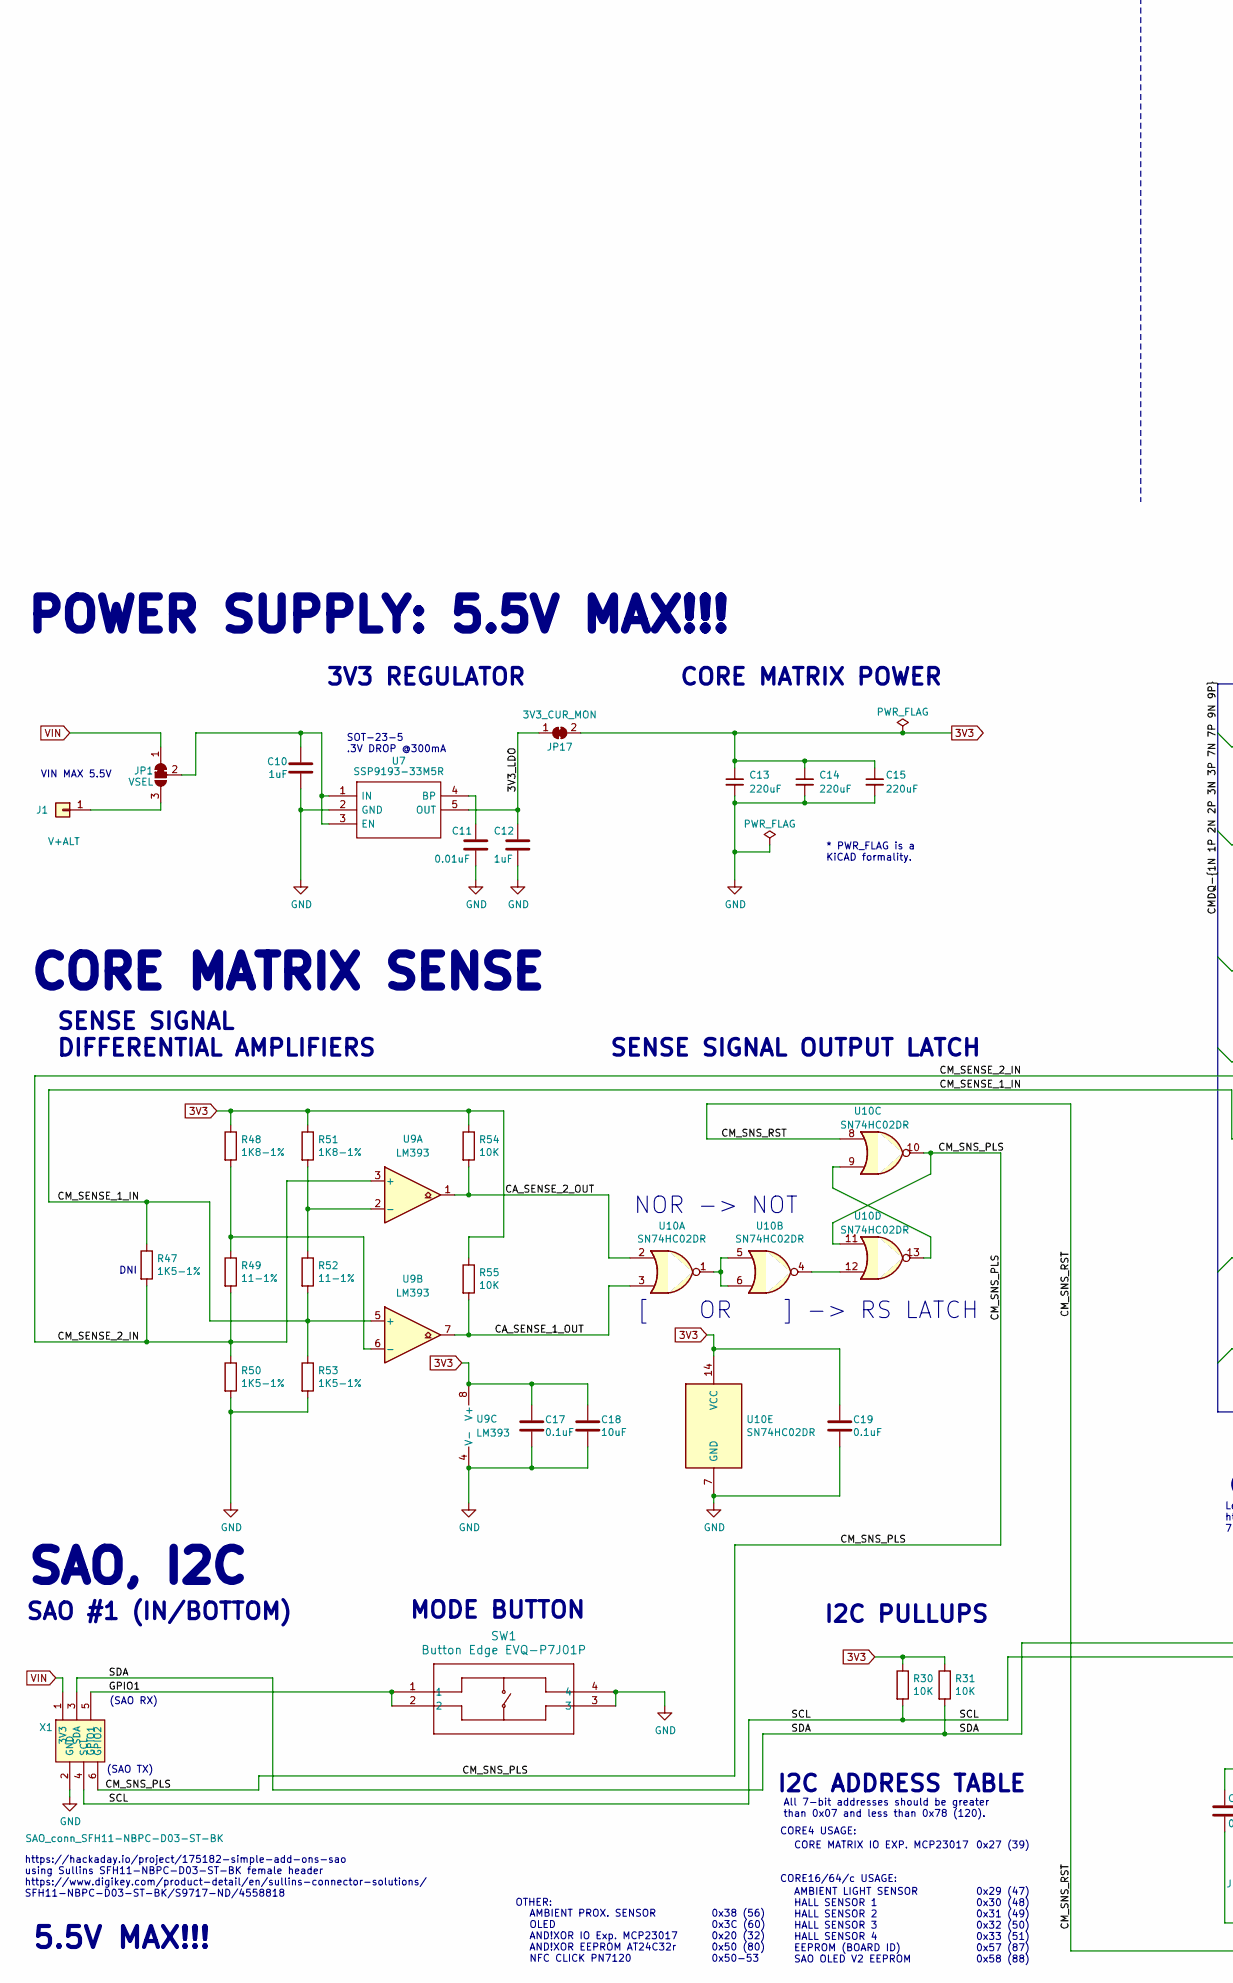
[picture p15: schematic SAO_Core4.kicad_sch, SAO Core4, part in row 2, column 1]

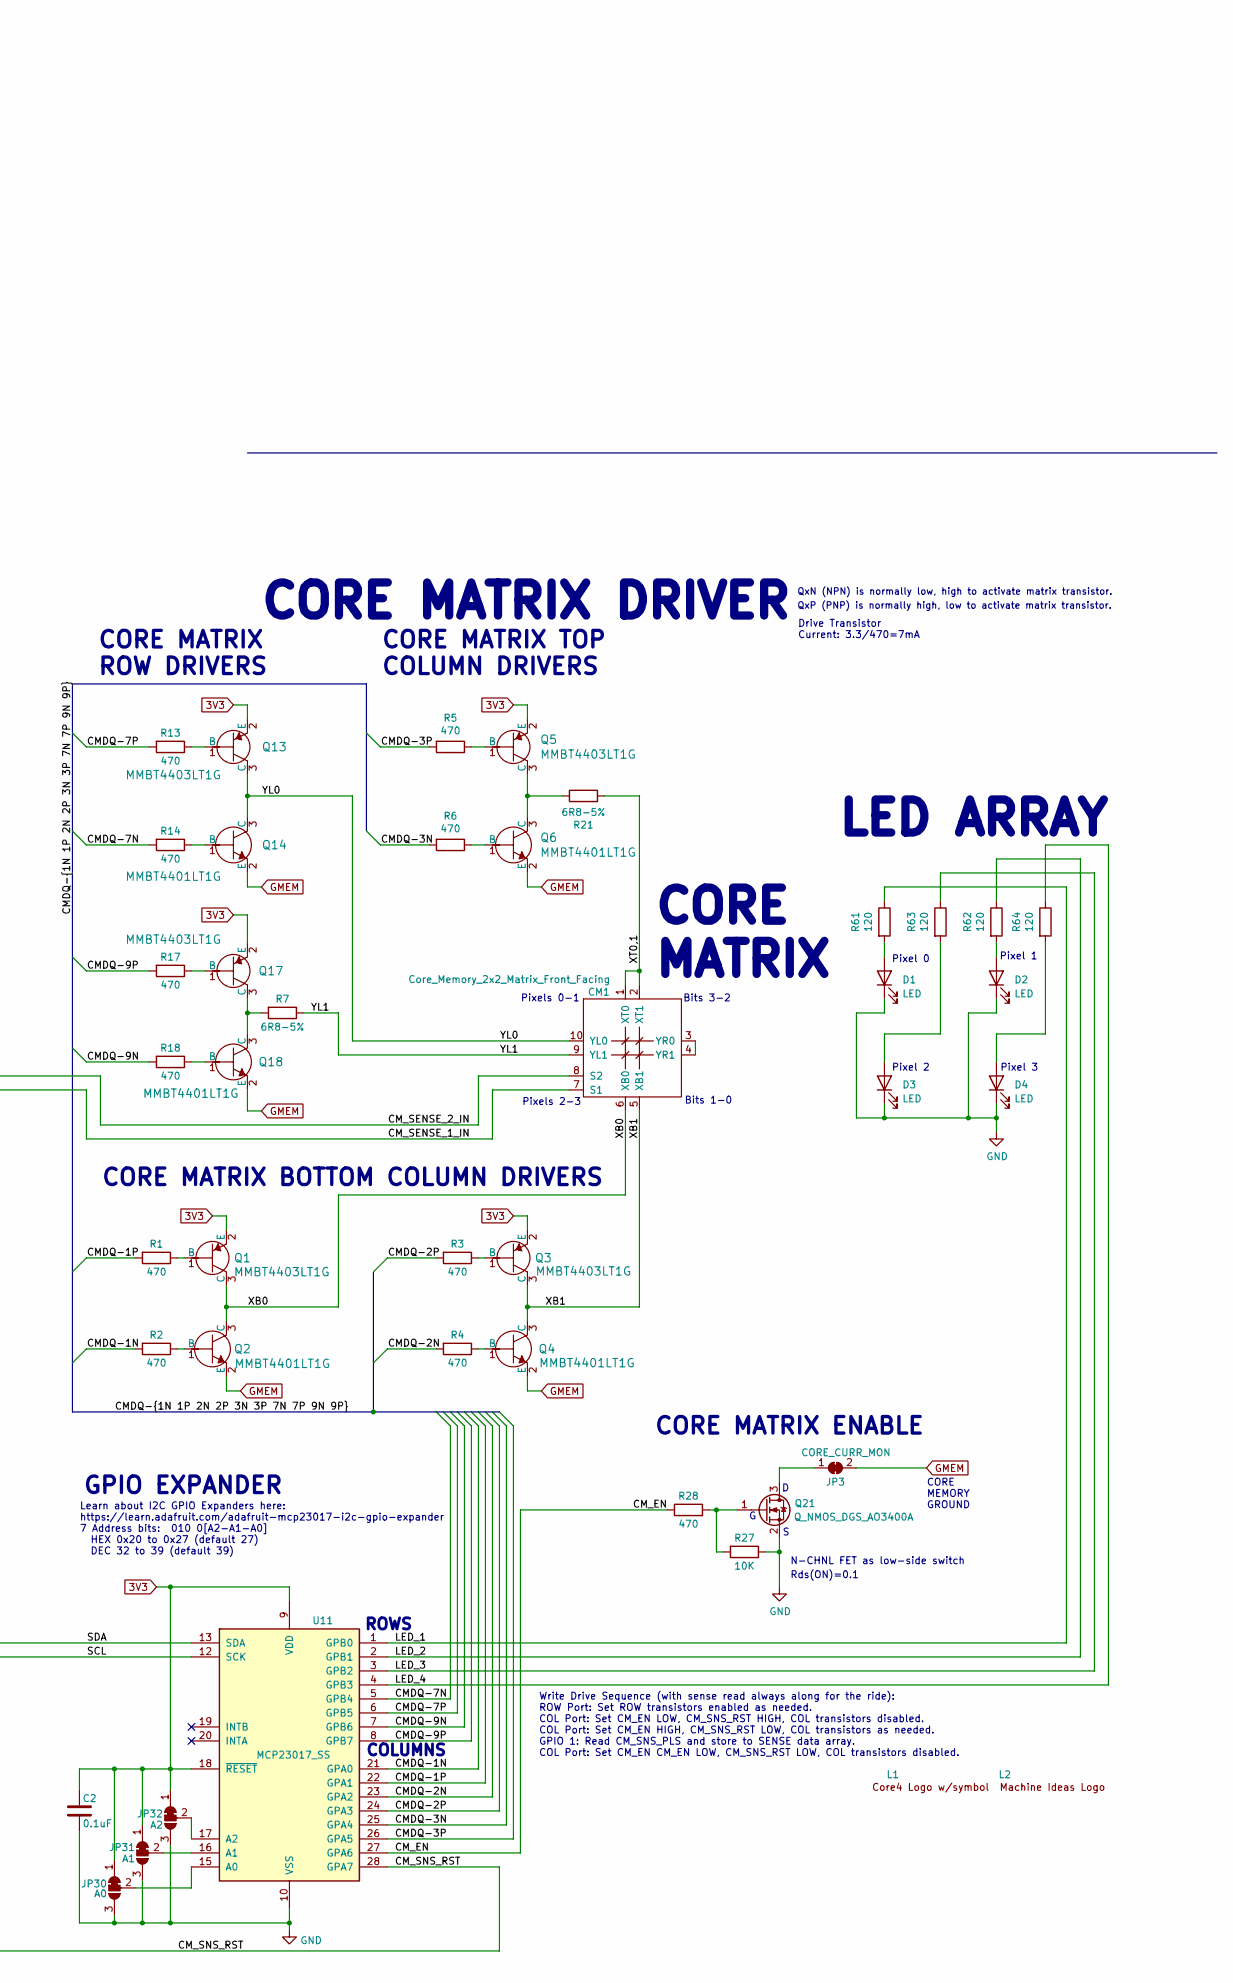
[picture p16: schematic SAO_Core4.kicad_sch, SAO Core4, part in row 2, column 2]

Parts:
C2, C17, C19: 0.1uF; C_0805_2012Metric; LCSC C28233
C10, C12: 1uF; C_0805_2012Metric; LCSC C28323
C11: 0.01uF; C_0805_2012Metric; LCSC C1710
C13, C14, C15: 220uF; C_1206_3216Metric; LCSC C412252
C18: 10uF; C_0805_2012Metric; LCSC C17024
CM1: Core_Memory_2x2_Matrix_Front_Facing; core_4_6.75mm_square_front_facing
D1, D2, D3, D4: LED; LED_1206_3216Metric_RevMnt_Hole1.8x2.4mm_custom; Manufacturer_Part_Number XL-3216UOC-FB; LCSC C3646936
J1: V+ALT; PinSocket_1x01_P1.27mm_Vertical
JP1: VSEL; SolderJumper-3_P1.3mm_Bridged12_Pad1.0x1.5mm
JP3: CORE_CURR_MON; SolderJumper-2_P1.3mm_Bridged_RoundedPad1.0x1.5mm
JP17: 3V3_CUR_MON; SolderJumper-2_P1.3mm_Bridged_RoundedPad1.0x1.5mm
JP30: A0; SolderJumper-3_P1.3mm_Bridged12_Pad1.0x1.5mm
JP31: A1; SolderJumper-3_P1.3mm_Bridged12_Pad1.0x1.5mm
JP32: A2; SolderJumper-3_P1.3mm_Bridged12_Pad1.0x1.5mm
L1: Core4_w_core_symbol
L2: Machine_Ideas_logo
Q1, Q3, Q5, Q13, Q17: MMBT4403LT1G; SOT-23-3; MPN MMBT4403LT1G; Digi-Key_PN MMBT4403LT1GOSCT-ND
Q2, Q4, Q6, Q14, Q18: MMBT4401LT1G; SOT-23-3; MPN MMBT4401LT1G; Digi-Key_PN MMBT4401LT1GOSCT-ND
Q21: Q_NMOS_DGS_AO3400A; SOT-23-3; LCSC C20917
R1, R2, R3, R4, R5, R6, R13, R14, R17, R18, R28: 470; R_0805_2012Metric; LCSC C17710
R7, R21: 6R8-5%; R_0805_2012Metric; LCSC C17774
R27, R30, R31, R54, R55: 10K; R_0805_2012Metric; LCSC C17414
R47, R50, R53: 1K5-1%; R_0805_2012Metric; LCSC C4310
R48, R51: 1K8-1%; R_0805_2012Metric; LCSC C17398
R49, R52: 11-1%; R_0805_2012Metric; LCSC C17430
R61, R62, R63, R64: 120; R_0805_2012Metric; LCSC C17437
SW1: Button Edge EVQ-P7J01P; SMD4_SW_EVQP7J_PAN; LCSC C2828254
U7: SSP9193-33M5R; SOT-23-5; Manufacturer_Part_Number SGM2007-3.3XN5/TR; Mouser Part Number SGM2007-3.3XN5/TR
U9: LM393; SOIC-8_W3.9mm; LCSC C7955
U10: SN74HC02DR; SOIC-14_3.9x8.7mm_P1.27mm; MPN SN74HC02DR; LCSC C6809
U11: MCP23017_SS; SSOP-28_5.3x10.2mm_P0.65mm; LCSC C506653
X1: SAO_conn_SFH11-NBPC-D03-ST-BK; Badgelife-SAOv169-BADGE-2x3-Edge-Connect-no-front-text; MPN SFH11-NBPC-D03-ST-BK

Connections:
3V3: C2.1, C13.1, C14.1, C15.1, C17.1, C18.1, C19.1, JP17.2 (B), JP30.1 (A), JP31.1 (A), JP32.1 (A), Q1.2 (E), Q3.2 (E), Q5.2 (E), Q13.2 (E), Q17.2 (E), R30.1, R31.1, R48.1, R51.1, R54.1, R55.1, U9.8 (V+), U10.14 (VCC), U11.9 (VDD), U11.18 (~RESET)
/3V3_LDO: C12.1, JP17.1 (A), U7.5 (OUT)
/CA_SENSE_1_OUT: R55.2, U9.7, U10.3
/CA_SENSE_2_OUT: R54.2, U9.1, U10.2
/CMDQ-1N: R2.2, U11.21 (GPA0)
/CMDQ-1P: R1.2, U11.22 (GPA1)
/CMDQ-2N: R4.2, U11.23 (GPA2)
/CMDQ-2P: R3.2, U11.24 (GPA3)
/CMDQ-3N: R6.2, U11.25 (GPA4)
/CMDQ-3P: R5.2, U11.26 (GPA5)
/CMDQ-7N: R14.2, U11.5 (GPB4)
/CMDQ-7P: R13.2, U11.6 (GPB5)
/CMDQ-9N: R18.2, U11.7 (GPB6)
/CMDQ-9P: R17.2, U11.8 (GPB7)
/CM_EN: R28.1, U11.27 (GPA6)
/CM_SENSE_1_IN: CM1.7 (S1), R47.1, R52.2, R53.1, U9.5 (+)
/CM_SENSE_2_IN: CM1.8 (S2), R47.2, R49.2, R50.1, U9.3 (+)
/CM_SNS_PLS: U10.10, U10.11, X1.6 (GPIO2)
/CM_SNS_RST: U10.8, U11.28 (GPA7)
/GPIO1: SW1.1, SW1.2, X1.5 (GPIO1)
/LED_1: R61.1, U11.1 (GPB0)
/LED_2: R62.1, U11.2 (GPB1)
/LED_3: R63.1, U11.3 (GPB2)
/LED_4: R64.1, U11.4 (GPB3)
/SCL: R30.2, U11.12 (SCK), X1.4 (SCL)
/SDA: R31.2, U11.13 (SDA), X1.3 (SDA)
/XB0: CM1.6 (XB0), Q1.3 (C), Q2.3 (C)
/XB1: CM1.5 (XB1), Q3.3 (C), Q4.3 (C)
/XT0,1: CM1.1 (XT0), CM1.2 (XT1), R21.2
/YL0: CM1.10 (YL0), Q13.3 (C), Q14.3 (C)
/YL1: CM1.9 (YL1), R7.1
GMEM: JP3.2 (B), Q2.2 (E), Q4.2 (E), Q6.2 (E), Q14.2 (E), Q18.2 (E)
GND: C2.2, C10.2, C11.2, C12.2, C13.2, C14.2, C15.2, C17.2, C18.2, C19.2, D1.1 (K), D2.1 (K), D3.1 (K), D4.1 (K), JP30.3 (B), JP31.3 (B), JP32.3 (B), Q21.2 (S), R27.1, R50.2, R53.2, SW1.3, SW1.4, U7.2 (GND), U9.4 (V-), U10.7 (GND), U11.10 (VSS), X1.2 (GND)
unnamed: CM1.3 (YR0), CM1.4 (YR1)
unnamed: D1.2 (A), R61.2
unnamed: D2.2 (A), R62.2
unnamed: D3.2 (A), R63.2
unnamed: D4.2 (A), R64.2
unnamed: J1.1, JP1.3 (B)
unnamed: C10.1, JP1.2 (C), U7.1 (IN), U7.3 (EN)
unnamed: JP3.1 (A), Q21.3 (D)
unnamed: JP30.2 (C), U11.15 (A0)
unnamed: JP31.2 (C), U11.16 (A1)
unnamed: JP32.2 (C), U11.17 (A2)
unnamed: Q1.1 (B), R1.1
unnamed: Q2.1 (B), R2.1
unnamed: Q3.1 (B), R3.1
unnamed: Q4.1 (B), R4.1
unnamed: Q5.1 (B), R5.1
unnamed: Q5.3 (C), Q6.3 (C), R21.1
unnamed: Q6.1 (B), R6.1
unnamed: Q13.1 (B), R13.1
unnamed: Q14.1 (B), R14.1
unnamed: Q17.1 (B), R17.1
unnamed: Q17.3 (C), Q18.3 (C), R7.2
unnamed: Q18.1 (B), R18.1
unnamed: Q21.1 (G), R27.2, R28.2
unnamed: C11.1, U7.4 (BP)
unnamed: R51.2, R52.1, U9.2 (-)
unnamed: R48.2, R49.1, U9.6 (-)
unnamed: U10.1, U10.5, U10.6
unnamed: U10.4, U10.12
unnamed: U10.9, U10.13
VIN: JP1.1 (A), X1.1 (3V3)

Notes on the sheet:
Bits 1-0
Pixel 0
QxP (PNP) is normally high, low to activate matrix transistor.
NOR -> NOT
AMBIENT PROX. SENSOR OLED AND!XOR IO Exp. MCP23017 AND!XOR EEPROM AT24C32r NFC CLICK PN7120
https://hackaday.io/project/175182-simple-add-ons-sao using Sullins SFH11-NBPC-D03-ST-BK female header https://www.digikey.com/product-detail/en/sullins-connector-solutions/ SFH11-NBPC-D03-ST-BK/S9717-ND/4558818
Bits 3-2
CORE MEMORY GROUND
N-CHNL FET as low-side switch
SENSE SIGNAL OUTPUT LATCH
[ OR ] -> RS LATCH
CORE MATRIX ROW DRIVERS
CORE4 USAGE:
CORE MATRIX IO EXP. MCP23017
Pixels 0-1
CORE MATRIX BOTTOM COLUMN DRIVERS
SOT-23-5 .3V DROP @300mA
MODE BUTTON
0x29 (47) 0x30 (48) 0x31 (49) 0x32 (50) 0x33 (51) 0x57 (87) 0x58 (88)
QxN (NPN) is normally low, high to activate matrix transistor.
ROWS
Pixel 2
COLUMNS
* PWR_FLAG is a KiCAD formality.
Pixel 1
GPIO EXPANDER
Rds(ON)=0.1
AMBIENT LIGHT SENSOR HALL SENSOR 1 HALL SENSOR 2 HALL SENSOR 3 HALL SENSOR 4 EEPROM (BOARD ID) SAO OLED V2 EEPROM
CORE MATRIX ENABLE
POWER SUPPLY: 5.5V MAX!!!
Drive Transistor Current: 3.3/470=7mA
CORE MATRIX DRIVER
CORE MATRIX TOP COLUMN DRIVERS
5.5V MAX!!!
3V3 REGULATOR
VIN MAX 5.5V
(SAO TX)
Write Drive Sequence (with sense read always along for the ride): ROW Port: Set ROW transistors enabled as needed. COL Port: Set CM_EN LOW, CM_SNS_RST HIGH, COL transistors disabled. COL Port: Set CM_EN HIGH, CM_SNS_RST LOW, COL transistors as needed. GPIO 1: Read CM_SNS_PLS and store to SENSE data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
0x38 (56) 0x3C (60) 0x20 (32) 0x50 (80) 0x50-53
SAO #1 (IN/BOTTOM)

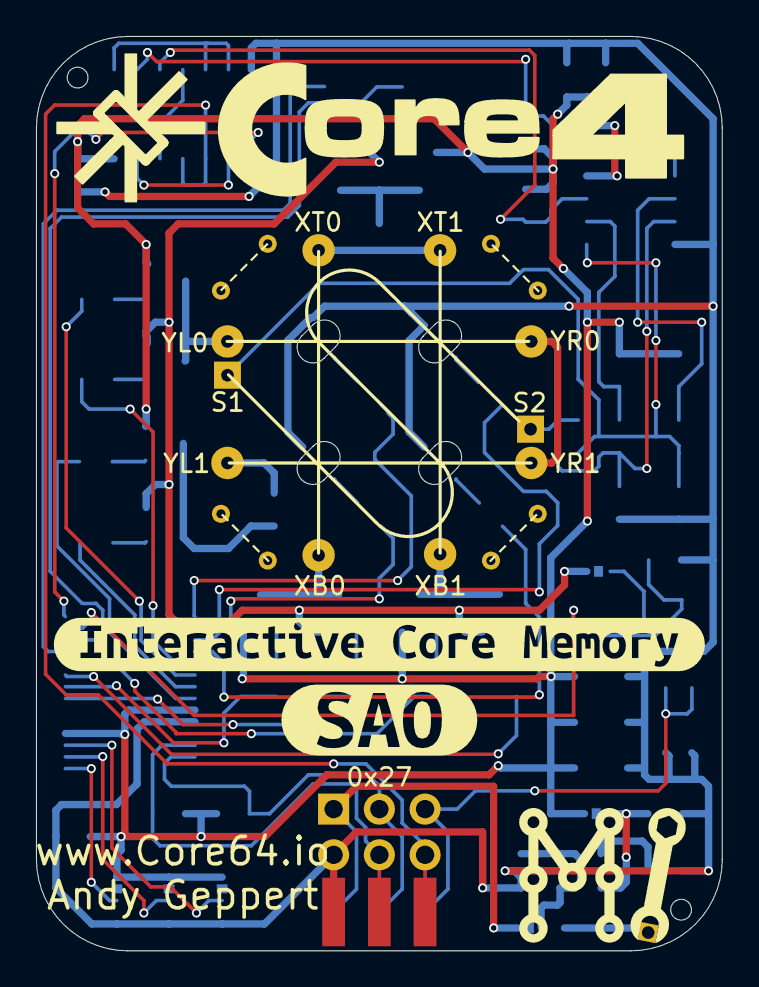
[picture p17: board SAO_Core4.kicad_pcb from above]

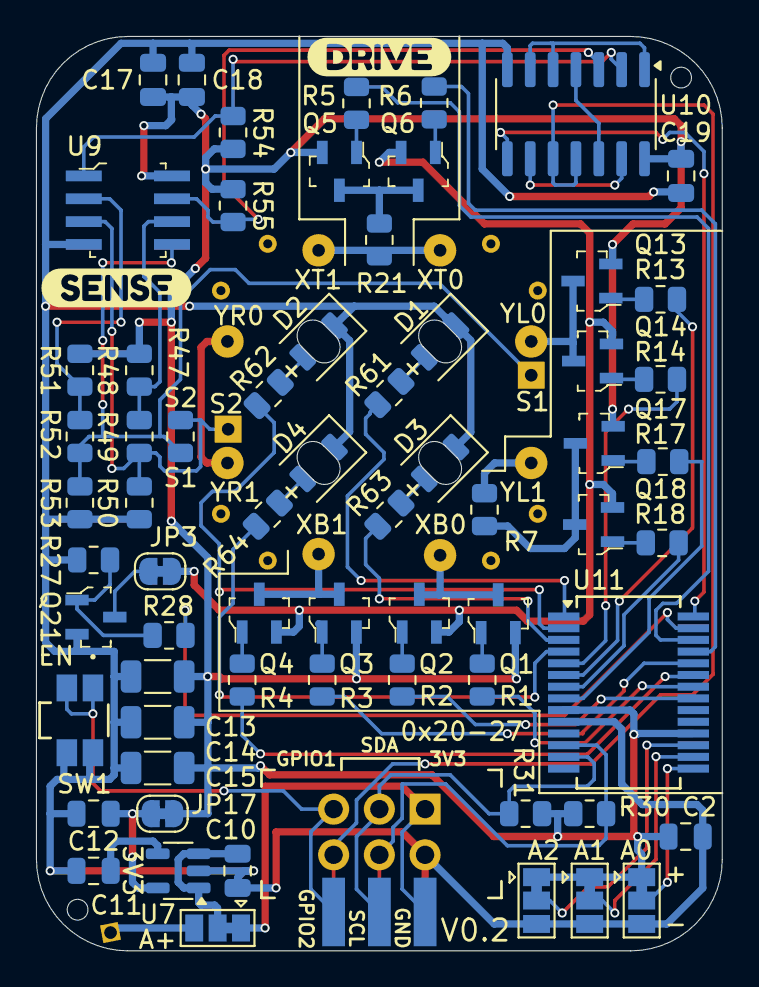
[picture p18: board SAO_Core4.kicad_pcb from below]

Board: 2 copper layers, 38.1 x 50.8 mm, 74 parts (68 on the bottom side), 64 nets.

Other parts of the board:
kibuzzard-66D35F07: G***; kibuzzard-66D35F07
kibuzzard-66D35F61: G***; kibuzzard-66D35F61
kibuzzard-64178DE8: G***; kibuzzard-64178DE8
kibuzzard-64178DF4: G***; kibuzzard-64178DF4

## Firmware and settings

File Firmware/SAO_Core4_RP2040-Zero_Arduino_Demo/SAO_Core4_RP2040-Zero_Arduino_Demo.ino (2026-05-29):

/* SAO Core4 Demo with Arduino 
  Github repo for SAO Core4:  https://github.com/ageppert/SAO_CORE4
  Project page for SAO Core4: https://hackaday.io/project/197235-sao-core4-a-nibble-of-core-memory-with-i2c

  Dependencies. 
    This demo will work with a huge range of IDEs and hardware, but it was developed and tested with the following:
    Arduino IDE 2.3.2 
      Install "Arduino Mbed OS RP2040 Boards" v4.1.5 with Arduino Boards Manager
      The Wire Library is included.
    RP2040-Zero (miniature Pico/RP2040 dev board) https://www.waveshare.com/rp2040-zero.htm

  Learn more about the IO Expander and ways to methods to drive it:
    https://tronixstuff.com/2011/08/26/arduino-mcp23017-tutorial/ (just uses Wire I2C directly by controlling the registers)
    https://learn.adafruit.com/adafruit-mcp23017-i2c-gpio-expander/arduino (uses Adafruit MCP23017 library, not used in this demo)
    https://www.makerguides.com/using-gpio-expander-mcp23017-with-arduino/ (uses Adafruit MCP23017 library, not used in this demo)

  Hardware Connections
    The bottom SAO port (X1) is intended to provide full access to the Core4 Matrix, LEDs, and sense circuit reset.
    SAO I2C pins connect to the GPIO Expander chip (MCP23017) which controls the core matrix transistors and LEDs.
    SAO GPIO1 enables power to the core matrix drive transistors
    SAO GPIO2 sense a core flip (change of the magnetic field from CW to CCW or vice versa, in the ferrite core)
  
    SAO I2C Pins are connected to the GPIO expander MCP23017 SDA and SCL pins
      All MCP23017 pins are configured as output.

    Default IO accessed by SAO GPIO pins, directly
      SAO_GPIO1 = unused, available
      SAO_GPIO2 = INPUT Core Matrix Sense, default low, unsensed
*/
  /***************************************** CORE4 HARDWARE VERSION TABLE *******************************************
  | VERSION |  DATE      | MCU     | DESCRIPTION                                                                    |
  -------------------------------------------------------------------------------------------------------------------
  |  0.1.0  | 2024-08-23 | RP2040  | First prototype, as built. Confusing row drive logic! Modified to 0.1.1 right away!
  |  0.1.1  | 2024-08-31 | RP2040  | Rework 0.1.0, isolate GPB0/1 for 7N/7P, route GPB6/7 to 9N/9P, connect GPA6 
  |         |            |         |   directly to CM_EN with JP25.
  |  0.2.0  | 2024-10-01 | RP2040  | Reduce overall size, simplify. Move YL0s to GPB4/5. Shift LED1-4 up to GPB0-3.
  |         |            |         |
  -----------------------------------------------------------------------------------------------------------------*/
// ------------------------------------
// USER OPTIONS
// ------------------------------------
//#define HWV_0_1_1                         // Choose the hardware version of SAO Core4 that you are using.
#define HWV_0_2_0                         // Choose the hardware version of SAO Core4 that you are using.
#define NeoPixel_Enable                   // Setup for the RP2040-Zero used in my SAO Demo Controller.
#define ENABLE_MEMORY_GAME                // After the blinky start-up sequence, and 15s in flux detector mode, begin the game of memory.
#define MCU_FAMILY              RP2040    // Keep track of what MCU this demo is set up for.

// ------------------------------------
// CONFIGURATIONS BASED ON USER OPTIONS
// ------------------------------------
#if defined HWV_0_1_1
  #define HARDWARE_VERSION_MAJOR  0
  #define HARDWARE_VERSION_MINOR  1
  #define HARDWARE_VERSION_PATCH  1
#elif defined HWV_0_2_0
  #define HARDWARE_VERSION_MAJOR  0
  #define HARDWARE_VERSION_MINOR  2
  #define HARDWARE_VERSION_PATCH  0
#else
  #error ("Hardware version undefined or unsupported.")
#endif

#if defined NeoPixel_Enable
  #include <Adafruit_NeoPixel.h>
  #define PIN        16
  #define NUMPIXELS   1
  Adafruit_NeoPixel pixels(NUMPIXELS, PIN, NEO_RGB + NEO_KHZ800);
  int ledState = 0;
#endif

#include <Wire.h>                           // RP204 Pico-Zero default I2C port is GPIO4 is SDA0, GPIO5 is SCL0
#define IO_EXPANDER_ADDRESS         0x27    // SAO Core4 default MCP23017 address is 0x27
#define IO_EXPANDER_REG_PORTA_DIR   0x00
#define IO_EXPANDER_REG_PORTB_DIR   0x01
#define IO_EXPANDER_REG_PORTA_DATA  0x12
#define IO_EXPANDER_REG_PORTB_DATA  0x13
static bool LEDArray[4] =  {0, 0, 0, 0};    // Default all four LEDs off.

#if defined (HWV_0_1_1)
  #define IO_PB_LED_ARRAY_START_BIT      2
  #define IO_PA_CORE_MATRIX_ENABLE_BIT   6
  #define IO_PA_SENSE_RESET_BIT          7
  uint8_t IOPortAInactive = 0b00101010;
  /*                          ||||||||__GPA0 : COLUMN Core Matrix Drive Transistor CMDQ-1N, XB0, default low, inactive
                              |||||||___GPA1 : COLUMN Core Matrix Drive Transistor CMDQ-1P, XB0, default high, inactive
                              ||||||____GPA2 : COLUMN Core Matrix Drive Transistor CMDQ-2N, XB1, default low, inactive
                              |||||_____GPA3 : COLUMN Core Matrix Drive Transistor CMDQ-2P, XB1, default high, inactive
                              ||||______GPA4 : COLUMN Core Matrix Drive Transistor CMDQ-3N, XT0,1, default low, inactive
                              |||_______GPA5 : COLUMN Core Matrix Drive Transistor CMDQ-3P, XT0,1, default high, inactive
                              ||________GPA6 : Core Matrix Enable, default low, inactive
                              |_________GPA7 : Core Matrix Sense Reset, default low, inactive */
  uint8_t IOPortBInactive = 0b10000010;
  /*                          ||||||||__GPB0 : ROW Core Matrix Drive Transistor CMDQ-7N, YL0, default low, inactive
                              |||||||___GPB1 : ROW Core Matrix Drive Transistor CMDQ-7P, YL0, default high, inactive
                              ||||||____GPB2 : LED_1 / Pixel 0, default low, inactive
                              |||||_____GPB3 : LED_2 / Pixel 1, default low, inactive
                              ||||______GPB4 : LED_3 / Pixel 2, default low, inactive
                              |||_______GPB5 : LED_4 / Pixel 3, default low, inactive
                              ||________GPB6 : ROW Core Matrix Drive Transistor CMDQ-9N, YL1, default low, inactive
                              |_________GPB7 : ROW Core Matrix Drive Transistor CMDQ-9P, YL1, default high, inactive */
#elif defined (HWV_0_2_0)
  #define IO_PB_LED_ARRAY_START_BIT      0
  #define IO_PA_CORE_MATRIX_ENABLE_BIT   6
  #define IO_PA_SENSE_RESET_BIT          7
  uint8_t IOPortAInactive = 0b00101010;
  /*                          ||||||||__GPA0 : COLUMN Core Matrix Drive Transistor CMDQ-1N, XB0, default low, inactive
                              |||||||___GPA1 : COLUMN Core Matrix Drive Transistor CMDQ-1P, XB0, default high, inactive
                              ||||||____GPA2 : COLUMN Core Matrix Drive Transistor CMDQ-2N, XB1, default low, inactive
                              |||||_____GPA3 : COLUMN Core Matrix Drive Transistor CMDQ-2P, XB1, default high, inactive
                              ||||______GPA4 : COLUMN Core Matrix Drive Transistor CMDQ-3N, XT0,1, default low, inactive
                              |||_______GPA5 : COLUMN Core Matrix Drive Transistor CMDQ-3P, XT0,1, default high, inactive
                              ||________GPA6 : Core Matrix Enable, default low, inactive
                              |_________GPA7 : Core Matrix Sense Reset, default low, inactive */
  uint8_t IOPortBInactive = 0b10100000;
  /*                          ||||||||__GPB0 : LED_1 / Pixel 0, default low, inactive
                              |||||||___GPB1 : LED_2 / Pixel 1, default low, inactive
                              ||||||____GPB2 : LED_3 / Pixel 2, default low, inactive 
                              |||||_____GPB3 : LED_4 / Pixel 3, default low, inactive 
                              ||||______GPB4 : ROW Core Matrix Drive Transistor CMDQ-7N, YL0, default low, inactive
                              |||_______GPB5 : ROW Core Matrix Drive Transistor CMDQ-7P, YL0, default high, inactive
                              ||________GPB6 : ROW Core Matrix Drive Transistor CMDQ-9N, YL1, default low, inactive
                              |_________GPB7 : ROW Core Matrix Drive Transistor CMDQ-9P, YL1, default high, inactive */
#else
  #error ("Hardware version undefined or unsupported.")
#endif

uint8_t IOPortA = IOPortAInactive;
uint8_t IOPortB = IOPortBInactive;
#define PIN_SAO_GPIO_1_MODE   26      // Configured as input for mode switching or general user use.
#define PIN_SAO_GPIO_2_SENSE  27      // Configured as input for sensing the core flip.
bool CMSenseArray[4] = {0,0,0,0};     // Store the most recent sense signal status for each core.
// These arrays set the row and column transistors correctly to address a given pixel with current in the correct direction.
// Pixel is 0 to 3. Value is 0 or 1. The value of 1 is arbitrarily defined by upper left Pixel 0 core with both wires + in upper left.
// CMDColPA = Core Matrix Drive Columns on Port A
static uint8_t CMDColPA[4][2] = {
//{0b00101010, 0b00101010}, default reference for each transistor to be inactive
  {0b00111000, 0b00001011}, 
  {0b00110010, 0b00001110},
  {0b00111000, 0b00001011},
  {0b00110010, 0b00001110}
/*     ||||||      ||||||__GPA0 : CMDQ-1N, XB0
       ||||||      |||||___GPA1 : CMDQ-1P, XB0
       ||||||      ||||____GPA2 : CMDQ-2N, XB1
       ||||||      |||_____GPA3 : CMDQ-2P, XB1
       ||||||      ||______GPA4 : CMDQ-3N, XT0,1
       ||||||      |_______GPA5 : CMDQ-3P, XT0,1
       ||||||__GPA0 : CMDQ-1N, XB0
       |||||___GPA1 : CMDQ-1P, XB0
       ||||____GPA2 : CMDQ-2N, XB1
       |||_____GPA3 : CMDQ-2P, XB1
       ||______GPA4 : CMDQ-3N, XT0,1
       |_______GPA5 : CMDQ-3P, XT0,1
       ______      _______
         |             |______ to write a one
         |____________________ to write a zero */
};
#if defined (HWV_0_1_1)
  static uint8_t CMDRowPB[4][2] {
  //{0b10000010, 0b10000010}, default reference for each transistor to be inactive
    {0b00000011, 0b11000000},
    {0b00000011, 0b11000000},
    {0b11000000, 0b00000011},
    {0b11000000, 0b00000011}
  /*   ||    ||    ||    ||__GPB0 : CMDQ-7N, YL0
       ||    ||    ||    |___GPB1 : CMDQ-7P, YL0
       ||    ||    ||________GPB6 : CMDQ-9N, YL1
       ||    ||    |_________GPB7 : CMDQ-9P, YL1
       ||    ||__GPB0 : CMDQ-7N, YL0
       ||    |___GPB1 : CMDQ-7P, YL0
       ||________GPB6 : CMDQ-9N, YL1
       |_________GPB7 : CMDQ-9P, YL1
       ________     ________
           |             |______ to write a one
           |____________________ to write a zero */
  };
#elif defined (HWV_0_2_0)
  static uint8_t CMDRowPB[4][2] {
  //{0b10100000, 0b10100000}, default reference for each transistor to be inactive
    {0b00110000, 0b11000000},
    {0b00110000, 0b11000000},
    {0b11000000, 0b00110000},
    {0b11000000, 0b00110000}
  //{0b10100000, 0b10100000}, default reference for each transistor to be inactive
//    {0b11000000, 0b00110000}, // 9N 7P, 9P 7N
//    {0b11000000, 0b00110000},
//    {0b00110000, 0b11000000},
//    {0b00110000, 0b11000000}
  /*   ||||        ||||______GPB4 : CMDQ-7N, YL0
       ||||        |||_______GPB5 : CMDQ-7P, YL0
       ||||        ||________GPB6 : CMDQ-9N, YL1
       ||||        |_________GPB7 : CMDQ-9P, YL1
       ||||______GPB4 : CMDQ-7N, YL0
       |||_______GPB5 : CMDQ-7P, YL0
       ||________GPB6 : CMDQ-9N, YL1
       |_________GPB7 : CMDQ-9P, YL1
       ________     ________
           |             |______ to write a one
           |____________________ to write a zero */
  };
#else
  #error ("Hardware version undefined or unsupported.")
#endif

enum TopLevelMode                       // Top Level Mode State Machine
{
  MODE_INIT,
  MODE_DAZZLE,   
  MODE_FLUX_TEST,   
  MODE_GAME_OF_MEMORY,   
  MODE_AT_THE_END_OF_TIME
} ;
uint8_t  TopLevelMode = MODE_INIT;
uint8_t  TopLevelModeDefault = MODE_DAZZLE;
uint32_t ModeTimeoutDeltams = 0;
uint32_t ModeTimeoutFirstTimeRun = true;
uint8_t  CoreTestStart = 0; // Default (0) is to test all four.
uint8_t  CoreTestLimit = 4; // Default (4) is to test all four.

void setup()
{
  // Nothing to see here. Everything runs in a simple state machine in the main loop function, and the bottom of this file.
  // This makes the conversion to using VSCode slightly easier.
}

bool SerialInit() {
  bool StatusSerial = 1;
  Serial.begin(115200);
  // TODO get rid of this delay, quickly detect presence of serial port, and send message only if it's detected.
  delay(1500);
  Serial.println("\nHello World! This is the serial port talking...");
  return StatusSerial;
}

void IOExpanderSafeStates() {
  Wire.beginTransmission(IO_EXPANDER_ADDRESS);
  Wire.write(IO_EXPANDER_REG_PORTA_DATA);
  Wire.write(IOPortAInactive);
  Wire.endTransmission();
  Wire.beginTransmission(IO_EXPANDER_ADDRESS);
  Wire.write(IO_EXPANDER_REG_PORTB_DATA);
  Wire.write(IOPortBInactive);
  Wire.endTransmission();
}

bool IOExpanderInit() {
  Serial.print("Core4: INIT IO Expander started... ");
  bool StatusIOExpander = 1;                      // default 0 = I2C MCP23017 not found, or 1 = I2C MCP23017 is found
  // TODO: detect MCP23017 and set status flag
  Wire.begin();                                   // wake up I2C bus, one time only
  Serial.print(" set data port to safe/inactive state,");
  IOExpanderSafeStates();
  Serial.print(" set all ports as ouput ");
  Wire.beginTransmission(IO_EXPANDER_ADDRESS);
  Wire.write(IO_EXPANDER_REG_PORTA_DIR);
  Wire.write(0x00);
  Wire.endTransmission();
  Wire.beginTransmission(IO_EXPANDER_ADDRESS);
  Wire.write(IO_EXPANDER_REG_PORTB_DIR);
  Wire.write(0x00);
  Wire.endTransmission();
  Serial.print("...completed with status ");
  if (StatusIOExpander ) { Serial.println("PRESENT.");}
  else { Serial.println("NOT present.");}
  return StatusIOExpander;
}

void SAOGPIOPinInit (){
  pinMode(PIN_SAO_GPIO_2_SENSE, INPUT);
  pinMode(PIN_SAO_GPIO_1_MODE, INPUT_PULLUP);
}
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
void loop()
{
  switch(TopLevelMode) {
    case MODE_INIT: {
      SerialInit();
      Serial.println("Core4: Entered MODE_INIT.");
      IOExpanderInit();
      SAOGPIOPinInit();
      Serial.println("");
      Serial.println("  |-------------------------------------------------------------------------| ");
      Serial.println("  | Welcome to the SAO Core4 Demo with Arduino IDE 2.3.2 using RP2040-Zero! | ");
      Serial.println("  |-------------------------------------------------------------------------| ");
      Serial.println("");
      Serial.print("### Firmware configured for hardware version: ");
      Serial.print(HARDWARE_VERSION_MAJOR);
      Serial.print(".");
      Serial.print(HARDWARE_VERSION_MINOR);
      Serial.print(".");
      Serial.println(HARDWARE_VERSION_PATCH);
      ModeTimeOutCheckReset();
      #if defined NeoPixel_Enable
        Serial.println("### NeoPixel enabled.");
        pixels.begin();
        pixels.clear();
        pixels.show();
      #endif
      Serial.println("");
      TopLevelMode = TopLevelModeDefault;
      Serial.println("Core4: Leaving MODE_INIT.");
      break;
    }

    case MODE_DAZZLE: {
      #if defined NeoPixel_Enable
        pixels.setPixelColor(0, pixels.Color(0, 0, 0));
        pixels.show();
      #endif
      if (ModeTimeoutFirstTimeRun) { Serial.println("Core4: Entered MODE_DAZZLE."); }
      static uint8_t PixelToTurnOn = 0;
      // Update the pixel to be turned on
      switch (PixelToTurnOn) {
        case 0: { PixelToTurnOn = 1; break; }
        case 1: { PixelToTurnOn = 3; break; }
        case 3: { PixelToTurnOn = 2; break; }
        case 2: { PixelToTurnOn = 0; break; }
        default: { PixelToTurnOn = 0; break; }
      }
      // Update the LED array
      for (uint8_t i = 0; i < 4; i++) {
        if (PixelToTurnOn == i) { LEDArray[i] = 1; }
        else                    { LEDArray[i] = 0; }
      }
      LEDUpdate();        
      delay(40);
      #if defined NeoPixel_Enable
        pixels.setPixelColor(0, pixels.Color(0, 100, 0));
        pixels.show();
      #endif
      delay(60);

      if (ModeTimeOutCheck(3000)){ 
        ModeTimeOutCheckReset();
        LEDClear();
        LEDUpdate();
        TopLevelMode++; 
        Serial.println("Core4: Leaving MODE_DAZZLE.");
      }
      break;
    }

    case MODE_FLUX_TEST: {
      if (ModeTimeoutFirstTimeRun) { 
        Serial.println("Core4: Entered MODE_FLUX_TEST."); 
        ModeTimeoutFirstTimeRun = false;
        IOExpanderSafeStates();
        }
      // Write all core 0, and if they change state as expected, don't light up an LED.
      for (uint8_t i = CoreTestStart; i < (CoreTestLimit); i++) {
        CoreMemoryBitWriteWithSense(i,0);
        LEDArray[i] = !CMSenseArray[i];
      }
      LEDUpdate(); 
      // Write all core 1, and if they change state as expected, don't light up an LED.
      for (uint8_t i = CoreTestStart; i < (CoreTestLimit); i++) {
        CoreMemoryBitWriteWithSense(i,1);
        LEDArray[i] = !CMSenseArray[i];
      }
      LEDUpdate(); 

#ifdef ENABLE_MEMORY_GAME
     if (ModeTimeOutCheck(15000)){ 
       ModeTimeOutCheckReset();
       for (uint8_t i = 0; i < 4; i++) { LEDArray[i] = 0; }
       LEDUpdate();
       TopLevelMode = MODE_GAME_OF_MEMORY; 
       Serial.println("Core4: Leaving MODE_FLUX_TEST.");
     }
#endif

      // Check for SAO GPIO1 to go low and move to another mode.
      if ( !digitalRead(PIN_SAO_GPIO_1_MODE) ){
        Serial.println("Mode changed!");
        TopLevelMode = MODE_GAME_OF_MEMORY;
      }
      #if defined NeoPixel_Enable
        if (ledState == 0) { ledState = 5;}
        else { ledState = 0;}
        pixels.setPixelColor(0, pixels.Color(0, ledState, ledState));
        pixels.show();
        delay(25);
      #endif
      delay(20);
      break;
    }

    case MODE_GAME_OF_MEMORY: {
      #define GAME_MEMORY_SEQUENCE_MAX_LENGTH 255
      static uint8_t GameMemoryState = 0;                 // Game state machine
      static uint8_t GameMemorySequenceLength = GAME_MEMORY_SEQUENCE_MAX_LENGTH-1;        // Maximum length of the memory sequence (array starts at 0, so that counts. If this line is 2, then there are actually 3 positions to memorize initially)
      static uint8_t GameMemoryTestStepPosition;      // Progress point in the sequence, where test is currently being evaluated
      static uint8_t GameMemoryTestStepEnd;           // How many steps in the sequence have been completed successfully
      static bool    GameMemoryTestStepComplete;  // A step in the sequence has been matched successfully
      static bool    GameMemoryPartialComplete;   // A partial sequence has been matched successfully
      static bool    GameMemoryTestStepWrong;
      static bool    GameMemoryGameComplete;      // The whole game sequence has been matched successfully
      static uint8_t GameMemorySequenceArray[GAME_MEMORY_SEQUENCE_MAX_LENGTH];
      static uint8_t PixelToTurnOn = 0;
      static bool      CoreMemoryIsTouched   = false;       // Register a touch
      static bool      CoreMemoryWasTouched   = false;      // Flag to catch state transition
      static uint8_t   CoreMemoryWhichIsTouched = 0;        // Keep track of which core is or was being touched
      static uint8_t   CoreMemoryCountTouched = 0;          // Keep track of how many cores are being touched
      static bool      CoreMemoryIsReleased  = true;        // Register a release
      static bool      CoreMemoryJustReleased = false;      // Register JUST released for one time use
      static uint16_t  CoreMemoryIsReleasedDebounce = 0;    // Keep track of how many times through this state the core is not touched.
      static uint16_t  CoreMemoryIsReleasedThresh = 3;     // How many times through the loop to register cores as not touched.
      // static bool      GameOKtoProceedToSeqStep   = false;  // Flag to indicate the correct core was touched in the sequence and move forward.
      
      if (ModeTimeoutFirstTimeRun) { 
        Serial.println("Core4: Entered MODE_GAME_OF_MEMORY."); 
        ModeTimeoutFirstTimeRun = false; 
        IOExpanderSafeStates();
        LEDClear();
        LEDUpdate();        
        GameMemoryState = 0;
      }


      switch (GameMemoryState) {
        case 0: {                                               // Clear variables and game start-up sparkle LEDs.
          Serial.print("Core4: MODE_GAME_OF_MEMORY state: ");
          Serial.println(GameMemoryState); 
          GameMemoryTestStepPosition = 0;
          GameMemoryTestStepEnd = 0;
          GameMemoryTestStepComplete = false;    
          GameMemoryPartialComplete = false; 
          GameMemoryGameComplete = false;    
          CoreMemoryIsTouched   = false;   
          CoreMemoryWasTouched   = false;  
          CoreMemoryWhichIsTouched;    
          CoreMemoryCountTouched = 0;      
          CoreMemoryIsReleased  = true;    
          CoreMemoryJustReleased = false;  
          CoreMemoryIsReleasedDebounce = 0;
          GameMemoryTestStepWrong = false;
          GameMemoryState = 1;
          break;
        }

        case 1: {                                               // Generate all of the pixel positions for memory test.
          Serial.print("Core4: MODE_GAME_OF_MEMORY state: "); 
          Serial.println(GameMemoryState);
          LEDClear();
          LEDUpdate();
          for (uint8_t i = 0; i < GameMemorySequenceLength; i++) {
            GameMemorySequenceArray[i] = random(0, 4);
            // Update the LED array
            for (uint8_t j = 0; j < 4; j++) {
              if (GameMemorySequenceArray[i] == j) { LEDArray[j] = 1; }
              else                    { LEDArray[j] = 0; }
            }
            LEDUpdate();      
            delay(20);
            LEDClear();
            LEDUpdate();
            delay(2);
          }
          LEDClear();
          LEDUpdate();
          delay(500);
          GameMemoryState = 2;
          break; 
        }
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

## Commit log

2024-08-14 First draft in progress
    [SAO_Core4.kicad_pcb, SAO_Core4.kicad_sch]
2024-08-17 Refine
    Cleanup schematic, plan drive scheme, commit to CM_EN, spare IO.
    [SAO_Core4.kicad_pcb, SAO_Core4.kicad_sch]
2024-08-18 Refine schematic
    [SAO_Core4.kicad_pcb, SAO_Core4.kicad_sch]
2024-08-23 HWV0.1 as prototyped
    Design as released, files organized.
    [Production Confirmation BOM.xls, SAO Core4 v0.1 2024-08-21 BOM.xlsx, SAO_Core4.kicad_pcb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]
2024-08-23 Copy HWV0.1 to start HWV0.2 design files
    [SAO_Core4.kicad_pcb, SAO_Core4.kicad_sch]
2024-08-23 Clean-up schematic DRC
    [SAO_Core4.kicad_pcb, SAO_Core4.kicad_sch]
2024-08-31 Begin refinements for HWV0.2.0
    [SAO_Core4.kicad_pcb, SAO_Core4.kicad_sch]
2024-08-31 Begin demo code in Arduino with dazzling LEDs
2024-09-01 HWV0.2.0: Move silkscreen elements
    [SAO_Core4.kicad_pcb]
2024-09-01 Flux detect works in all cores with Arduino demo code
2024-09-01 Shrink V0.2 PCB size
    [SAO_Core4.kicad_pcb, SAO_Core4.kicad_sch]
2024-09-03 Move LED dazzle to occur with memory game randomizer in Arduino demo
2024-09-03 Add V0.1 to schematics and renders
2024-09-03 HWV0.2: Create WIP schematics pdf and renders
    [SAO_Core4.kicad_pcb, SAO_Core4.kicad_sch]
2024-09-10 Create assembly guide.
2024-09-10 Add schematic revision 0.1.1 redlines to Assembly Guide
2024-09-10 Add schematic revision V0.1.1 redlines
2024-09-10 HWV0.2: Denote as WIP
    [SAO_Core4.kicad_pcb, SAO_Core4.kicad_sch]
2024-09-21 Add delay after all core writes to reduce average current use
    [SAO_Core4.kicad_sch]
2024-10-10 Add SAo Core4 V0.2 files, demo code update
    [SAO Core4 v0.2 2024-09-23 BOM.xlsx, SAO_Core4.kicad_pcb, SAO_Core4.kicad_sch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]
2026-05-29 Fix Firmware Demo CoreMemoryBitWrite, default to HWV 0.2.0, default to NeoPixel enable
    Fully operational! Backed out changes that broke the operation of Game of Memory operation.
    [SAO_Core4_RP2040-Zero_Arduino_Demo.ino]
